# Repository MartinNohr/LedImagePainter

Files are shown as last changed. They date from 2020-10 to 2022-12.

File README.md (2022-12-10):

# LedImagePainter
New ESP32 version using rotary push button switch.
See https://www.thingiverse.com/thing:4613446 for details.
There is a switch in the .h file to add support for exFat (SDXC media) which will support SD cards > 32GB.
This library is needed: https://github.com/greiman/SdFat

See MagicImageWand for the very latest version of this project.

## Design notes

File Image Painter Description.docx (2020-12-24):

# LED Image Painter

# Introduction

## History

This design was inspired but not copied from the PixelStick commercial product. I have not owned, used or even touched an official PixelStick, I haven’t even read their manual. I did briefly look at the marketing material on their website to get an idea of how it worked. I was also inspired by the light wand developed by photographer Michael Ross. I started out building one of these. It used the Mega2560 Arduino and a 2-line display with some buttons. I started adding features and quickly ran out of memory. I also wanted to support a second 1-meter LED strip. At this point I decided to do a total rewrite and use the newer much faster esp32 modules. This let the feature list grow and the additionally the strip display speed was increased dramatically.

## Using with Your Camera

Put your camera on a tripod and set it for a long enough time exposure so the shutter is open for the time it takes to display the image. Stand at your chosen starting position and open the camera shutter. Press the Image Painter start button and walk from right to left (looking at the camera), or left to right if you prefer, it is adjustable from the menus. Walk smoothly or erratically for the effect you want and hold the wand in the same position or wave it around. Use your creativity and see what kinds of images you can create.

## Description

The Image Painter consists of the following major parts. The parts are all connected together into a single unit. The optional second LED strip is easily removed so the system fits into a smaller space.

1. LED strip. This is an aluminum extrusion with 144 LEDs and a diffuser cover. The LEDs are available with an adhesive backing that is used to stick the strip inside the extrusion.
2. Fixed Handle. The rotary control button is on the handle which is used to hold the Image Painter. The button is under your thumb and can be pushed and rotated.
3. Rotating Handle. This is useful when two LED strips are attached. It allows the user to spin the light stick.
4. Control Unit. This box holds the ESP32 computer that runs the LED strips and reads the rotary button switch.
  a. OLED Display. The ESP32 module used includes a small OLED display that is used to show the file selections. It is also used to show menus so that the various settings can be changed.
5. USB Battery. This is the rechargeable battery that runs the control unit and the LED strips.
6. Roller Encoder Wheel. This wheel is used to control the display speed while rolling on the ground. It will allow for very exact image timing. The good news is the software supports it, the bad news is that the hardware mount for the wheel has not been designed yet.

## 144 or 288 pixels

The Image Painter uses one or two WS3812B pixel strips that have 144 pixels per meter. In actuality each meter strip is made from two 72 pixel strips. This results in a slight gap in the middle that can be seen in some images. When the second strip is installed the power wires make it difficult to get the pixels really close. This also results in a dark gap in the middle of the two strips that can be seen with some images.

## Limitations

At full brightness each strip uses 43 Watts when all the LEDs are lit. Since the USB battery can only supply 35 Watts it is obvious that the display cannot be used at full brightness. However, some images do not have all of the LEDs lit at the same time so the brightness can sometimes be set to full power. For example, if the strip never has more than half of the LEDs on then the power consumption is only 21 Watts. This will work. In practice however I have found that due to the long night exposures it is seldom necessary to go brighter than about ¼ power.

## Processing BMP Images

The images can be either 144 or 288 pixels in height. They must be rotated 90 degrees CCW and saved as 24bit color in Windows byte order. They can be as long as desired in width.

# Examples

Here are a few example photos created with the Image Painter. People more creative than me will create much more interesting images. I’m including these just to illustrate a few simple examples. You can also go search the web for PixelStick images to get more inspiration.

# Button Operations

All operations can be controlled by the rotary push button on the handle, this makes the image painter usable with one hand. The display shows the options and settings and filenames. The dial can be rotated left or right to choose items. The button is clicked to select the current item. A long press is used to access other options and is done by holding the button down for about a ½ second or longer. This long press time is also adjustable if a longer or shorter time is preferred. The system has two modes of operation. After booting the display shows the currently selected file. Rotating the dial left and right will move through the files on the SD card, or the internal patterns if they have been selected. Clicking the button starts the LED strip display. At this point the user walks around with the wand or waves it around depending on what effect is desired. The display shows the progress of the file and how much time is remaining. Settings are available to control the display speed, repeating the file, or even automatically skipping to the next file. The image can even be played twice, first forward and then backward for a mirror like effect. There is a chain option that will play all of the files from the current selection to the final file in the current folder. The brightness of the LEDs are of course also adjustable to balance the lighting with the rest of the scene.

To adjust settings a long press is used which will open the last menu that was used. A long press while in the menus returns to the normal play mode. Each menu except the main menu has an entry to return to the previous menu.

## File Control Settings

There are more details below in the section on menus but here is a quick list of the things that can be changed for controlling the image display.

1. LED brightness.
2. Color Balance. Set the white balance for special effects or to correct color casts.
3. Gamma Correction. Adjust the display to match closer to our vision.
4. Frame hold time, how long each frame is displayed. Note that even when set to 0 there is a minimum frame time which is determined by the amount of time used to load the LED’s. See the menu section below for more details. Frame advance can also be set to manual so the frame only changes when the button is pressed or the dial is rotated.
5. Fixed display time. It is also possible to have the system calculate the frame hold time. You just set how long in seconds you want the image to take and it will set the correct frame time based on the image size.
6. Reverse. So the user can walk from left to right or vice versa.
7. Upside Down. This allows the user to hold the wand high in the air without modifying the image file.
8. Pixel Double. This uses two pixels for each one so a 144 pixel image can be displayed on the entire 288 pixels when two strips are installed.
9. Scaling. This will reduce a 288 pixel image to 144 pixels.
10. Mirror. Plays the file twice, first forward and then in reverse.
11. Chain. Plays all the files from the current file to the last file in the current folder. Files are always in alphabetical order.
12. Start Delay. A wait after pressing the button until the file starts. All delays are specified in 1/10 seconds.
13. Repeat Count. How many times to repeat a file.
14. Repeat Delay. A wait in between file repeats.
15. Chain Repeat. How many times to repeat a chain.
16. Chain Delay. A pause in between chain repeats.
17. Built-In or File. Choose files from the SD or from a set of built in patterns.
18. Change settings for various built-in patterns.
19. Select Folder. Choose a folder on the SD card to look for BMP files.
20. Display Settings. Control some menu operations and display options.
21. IPC. Manages files that change settings for folders and files. These setting files are loaded when a folder is selected or when a file is run. The settings for a file revert to the original values after running the file. These files are also text and can be edited if desired for special operations. The file version will apply the settings when the named file is displayed. The folder version is loaded when a folder is selected.
22. Saved Settings. Change the settings that can be optionally loaded at boot time. It is also possible to save the current settings and manually load them when needed.
23. Macros. There are ten macro slots (0 to 9) available. Each of these can either load all of the settings or run a recorded sequence of operations. The record command records the images as they are played and the same sequence can then be played again using the run command. The save command stores the current settings which can then be restored with the load command.
24. BLE. Enable BlueTooth. There is an Android app that can monitor and control the Image Painter. An iOS one may come later.
25. Reboot. This will reset the system. It can of course also be done by unplugging the USB power supply.

## Rotating and Clicking Button

The handle button is rotated and clicked to select different files, menu items, and to change settings. In the menus boolean values toggle with each click. Integer values go to another screen that shows the minimum and maximum values. Rotating the dial right increases the value while rotating to the left decreases it by the increment amount. The increment amount can be changed by clicking the button which will cycle between different values. One of the values will be a reset to the original value, activated with a long press. A long press is also used to accept the new value and return to the menu. A * indicates the active menu line. A + in front of the menu means another menu will be activated. The “Return…” menu goes back to the previous menu when clicked. A long press will return to file select/run mode. The current menu entry is remembered so that it will return to the same place when the long press is done from the select/run screen.

In select/run mode the current file is displayed on the top line. Optionally the next three files will be displayed below. Rotating the dial right moves the next file to the top line and rotating left moves the previous file back. By default it will stop at the first and the last file. An option allows rollover, so going left from the first file moves to the last file and moving right at the last file will display the first file again. This option also causes menus to behave similarly.

When a file is running after clicking the button the top of the display will show the progress of the file. The current filename is displayed. The line under the file will show the remaining seconds for the file. The rest of the screen will show the various delays, repeats, and chain information when those options are activated.

### Button Menu Operations

Left/ Right

Select menu

Select file

Inc/ Dec integers

Long press

Open menu system, goes to the remembered menu point

Return to run mode, the current menu point is remembered

Accept integer

Click

Run file when in run mode

Select menu item, including return to previous menu

Toggle booleans

# Menu Details

Following is a detailed list of all the menu entries and what they do. Menu items that open another menu (a submenu) start with a ‘+’. Most submenus also have a first and last menu entry that returns to the menu above. A ‘*’ is shown in front of the active menu line. The top menu will have a ‘-’ indicating that there are menu items that are not visible due to scrolling. Just keep rotating the knob to the left and they will appear. Similarly the last entry on the screen will have a ‘_’ if there are more menus below. Scroll right to make them visible as the ‘*’ indicator moves down.

The submenu details are also described below after each menu item.

## Main Menu

### Switch to Built-Ins/Switch to SD

Clicking this toggles between running files from the SD card or using the built-in patterns.

## File Image Settings

This submenu has the settings that control display attributes of the image files. The frame hold time is also used by some of the built-in image functions.

### Timing Type (Column or Image)

This is a Boolean that switches between using a set frame hold time for each column of the image file or a calculated time based on the desired total display time. It is sometimes more convenient to set the total time that the image file is displayed. This mode will automatically calculate the frame hold time such that the image will display for the chosen time. It is possible to request a time that is too fast for the image painter. If the calculated frame hold is less than about 4 mS the software cannot read the SD card fast enough to keep up. The image painter will try to do the best it can and the actual time will be displayed on the screen as the image plays.

### Frame Hold

When frame time is selected this is the time in mSecs (see note below) that each line of information from the BMP file is displayed on the LED strip. It is commonly used to adjust the walking time while the file is being displayed. It is only applicable when Frame Advance is set to auto.

Note: This time is actually added to the minimum time that it takes to update the LED’s in the strip. Each bit of information takes 1.2 uS and each LED needs 24 bits. If there are 144 LED’s then the total time to load the data is 1.2 uS x 24 x 144 = 4.32 mS. There is also a reset time at the end that loads the data into the LED’s of >50 uS. Some brands require up to 1 mS so it is safest to assume that the column update time is about 5 mS. This time is added to the time set in the frame hold value, I.E. a hold value of 0 will still have a 5 mS frame time. There might also be additional time required for reading slower SD cards. Also be aware that displaying the file in reverse will slow down due to reading the SD file in the reverse order. A 900 column image would in theory take about 3.9 S. In testing we have found that reading the SD card actually slows this down to about 6 Seconds. Work is being done to try and improve this.

### Fixed Time

When fixed time is selected as described above in Fixed/Frame Time this menu item allows the time to be set in seconds that the image will be displayed. The necessary frame hold time will be calculated and used while displaying the image file. This value will not be saved in the frame time so if frame hold is selected it will show the original value.

### Frame Advance

The options are “auto” and “manual”. In auto mode the frame hold time is used. In manual each line is displayed until the button is pressed, the dial is rotated, or the wheel pulse counter closes the contact. If the frame pulse counter is zero then the dial is used to advance frames. Rotating to the right or clicking will display the next frame from the file. Rotating to the left will display the previous frame. This enables some creative uses of image by rotating the wheel left and right. Note that the mechanical wheel pulse counter has not been designed yet.

### Frame Pulse Counter

This value is the number of wheel pulses that will advance to the next frame when manual frame advance is set. Note that this disables using the rotary dial to advance frames.

### Start Delay

This value delays the image display after the start button is pressed. It can be set in 1/10 seconds.

### Upside Down Image

When set, the image pixels will be reversed. This allows the LED bar to be held upside down without making the image upside down.

### Walk Direction

This option changes the direction that the file is read. This allows the image to play forward or reverse. This allows the user to walk in the other direction or to simply reverse the image from left to right. The default is right to left, looking back at the camera. Right to left is usually best when recording a sequence of images into a macro. The images will then play back in the same order. If left to right is chosen then the images recorded will play back in the reverse order. This is particularly important when spelling words with the individual letter image files.

### Play Mirror Image

This plays the image twice, once forward and then in reverse. This creates a mirror like effect.

### Scale Height to Fit

If the image is taller than 144/288 this option will ignore some pixels so that only 144/288 are actually displayed. It doesn’t do any fancy scaling like Photoshop by looking at adjacent pixels, it simply ignores some of them so the image will fit.

### 144 to 288 Pixels (only when 2 strips)

This doubles every pixel so a 144 pixel image will fill all 288 pixels. Of course there isn’t any increase in resolution, but it does fill two strips if you don’t have a 288 pixel image.

## Repeat Settings

This submenu contains settings that are used to repeat images. Except for the chaining option it also applies to built-in images.

### Repeat Count

This is the number of times to repeat an image.

### Repeat Delay

When repeat count is greater than one this value will cause a delay before the image starts again. It can be in 1/10’s seconds.

### Chain Files

When this option is on all the files from the current one to the end of the last file in the current folder will be displayed. Since filenames are always sorted alphabetically this option will show a sorted list of files. If some other order is desired it is also possible to use the macro command to record the file order for display.

### Chain Repeats (only when chain files on)

The entire chain will be repeated this many times.

## LED Strip Settings

This submenu has settings for the LED strip.

### Strip Brightness

This is the brightness from 1 to 255. It was originally from 1 to 100%, but it was found that this didn’t give very fine resolution of brightness on the low end, so it was decided to use the actual hardware value which has 255 level, not 100.

### LED Strips

This is set to “one” or “two” depending on whether you have the second strip installed. The designer didn’t figure out any way to automatically detect the second strip.

### Gamma Correction

This option modifies the displayed colors at different brightness levels to more closely match our eyes color perception.

### White Balance R

This manually sets the strip Red brightness.

### White Balance G

This manually sets the strip Green brightness.

### White Balance B

This manually sets the strip Blue brightness.

### Show White Balance

Selecting this displays the before and after result of setting the RGB levels.

## IPC File Operations

IPC files are files that can load settings and display images. They are text and can be modified by using any text editor on them. The extension is always IPC (Image Painter Command). There are menu items to create, run and delete them. Depending on the name some of them are automatically run under certain conditions as documented below.

IPC file only control the settings for files, none of the built-in image settings are saved in these files.

### Save start.ipc

This creates a file with the current settings. It is run whenever a folder is opened.

### Load start.ipc

This will manually run the file in the current folder.

### Erase start.ipc

This does just what it says: removes the start.ipc file from the current folder.

### Associated Files

These are command files just like the start.ipc file above, but they have the same name as a BMP file, but with the .ipc extension of course. The file is run when a BMP file is started for display. This allows specific settings to always be applied to a specified BMP file.

#### Save <filename>.ipc

This saves the current settings for the currently selected BMP file.

#### Load <filename>.ipc

This loads the settings for the currently selected BMP file. It can be used to verify that the settings are in fact correct.

#### Erase <filename>.ipc

This command deletes the file associated the currently selected BMP file.

## Macros

Macro files are a powerful feature that can be used to record and run a set of images. There are 10 macro files allowed. They are named from 0.ipc to 9.ipc on the SD card in the root folder. They can also be edited on a computer by using a text editor if necessary. The easiest way to create one is to use the record menu entry as shown below.

### Macro #(0-9)

This selects the current macro number. It shows a list of all the macros along with information on whether it already exists or not. Clicking on a line makes that macro # the active current macro # which is used by most of the following menu entries.

### Run

This will run the currently selected macro number.

### Repeat Count

This value repeats the macro run.

### Repeat Delay (S)

There can be a delay between each run of the macro when repeat is on.

### Recording

When set to true the settings and displayed images will be appended to the currently selected macro number. It should be turned off when all the actions have been recorded. Is the delete command if a sequence is to be started without appending.

### Load

This loads the settings in a macro file. It is best used in combination with the save command.

### Save

This saves the current settings in a macro file.

### Delete

This erases the currently selected macro file. It is useful when a new sequence is to be recorded since the default record action is to append new actions.

## Saved Settings

These settings are stored in the EEPROM section of the ESP32 and is a useful way to set all of the defaults during boot time.

There is a version number stored in EEPROM that will be compared when loading. I mismatch will cause an error message to appear. Saving the settings will clear this error.

### Autoload Saved

This flag causes the EEPROM values to be loaded at boot time. If off then the factory settings will be loaded instead. If factory settings are desired the button should be pressed during booting. This will ignore the setting of this flag.

There is some quirkiness in the code that will not allow this flag to be turned off until the settings have been saved at least once. This only happens the first time the software is loaded on a new ESP32 board. Using the “save current settings” command will fix this forever.

### Save Current Settings

This saves the current settings. Built-in options settings are also saved. Note that IPC files do note save any of the built-in settings.

### Load Saved Settings

This manually loads the settings from EEPROM.

## System Settings

Various system settings can be changed from this submenu. These include the display and various operations.

### Display Brightness

This is the TFT display brightness from 1 to 100%. It is often desirable to lower it when working in strong darkness.

### Display (Normal or Reverse)

This option reverses the colors on the display.

### Menu Wrap

When this is off scrolling of both files and menu items is pinned at the top and bottom of the list. If wrap is on then rotation the dial to the right when at the last entry will go to the first entry and rotation left from the first entry to move to the last entry.

### Show More Files

In run mode the top line always shows the file to be displayed. When this flag is on the following lines on the display will show the next few files in the current folder.

### Show Folder

The top line in run mode shows the current file to be run. If this flag is on it will include the folder path. It should be turned off if the folder path is too long.

### Progress Bar

When a file is running the top of the OLED display can show a progress bar. This option is used to turn it on or off.

### Dial (Normal or Reverse)

This sets the direction of the dial that moves forward or backward through choices.

### Dial Sensitivity

It is sometimes desirable to reduce the sensitivity of the dial to rotation. Wearing gloves or shivering fingers is an example. This allows a counter to be set such that more than one rotation detent will be required to produce a dial motion. For example, setting this to 2 means that the dial has to be moved two clicks before it would change the selection. Values from 1 to 5 can be set.

### Dial Speed

This value adjusts how fast the dial needs to be moved to work with the dial sensitivity setting. It is effectively the time between clicks. It can set from 100 to 1000 and is approximately a time value in mSeconds. If you have the sensitivity set to a number greater than 1 then you have to rotate the dial faster than this number allows in order to cause the selection to change.

### BlueTooth Link (On/Off)

This enables the BlueTooth link to be used with the phone app for control of the Image Painter.

## Light Bar

This selection turns the Image Painter into an adjust LED light source. All of the LED’s are turned on. The menu can then be used to change the Hue, saturation, and brightness levels. The maximum brightness is limited by the strip brightness that is set in the strip menu. This may be changed in the future so it will be possible to increase the brightness beyond that setting. Anybody have any strong thoughts on that?

The default allows setting the brightness, hue and saturation, but it can also be changed to use RGB values. The default increment unit is 10 for each click of the dial but that can also be adjust for finer resolution.

A long press is used to turn the light bar off again.

## Reboot

Just like unplugging the power and plugging it back in.

# Built-In Patterns

There are a number of built-in pattern generators. Some of them have settings that can be adjusted from the entry that appears on the first menu when a particular built-in is selected. The available built-ins are listed below.

## Barber Pole

This creates a rolling red, white, and blue pattern. It will create diagonal patterns. The speed is controllable by setting the frame hold time.

## Beats

Colored bars moving up and down.

## Bouncy Balls

This uses physics calculations to simulate some colored bouncing balls. The number of balls can be set up to 8, each will have its own color. The speed can be changed using the same built-in menu. The frame hold time is not used. On an image it makes some interesting decaying inverted second order polynomial traces. Sorry about the math terms! Play with it.

## Checker Board

Alternating black and white boxes. The speed is adjustable using the built-in menu or the frame hold time.

## Confetti

Interesting color dots that appear and then fade out.

## Cylon Eye

This was inspired from the BattleStar Galactica movies, the evil Cylon eyes.

## Juggle

This shows some color bars that move up and down and cross over each other.

## Meteor

This looks kind of like a meteor moving from one end of the strip to the other.

## One Dot

Actually, this is four dots, red, green, blue and white. They move one at a time from one end to the other. It is probably mostly useful for testing the wand. That’s why it was written originally.

## Rainbow

The color, number of repeats, and color cycling can be controlled. It is even possible to add random sparkles to add a bit more interest. Try moving the wand in an arc for interesting rainbow-like patterns.

## Random Bars

This produces solid colors that alternate randomly. An option sets black in between each color bar. Waving the wand can make some interesting patterns in the air.

## Rainbow Pulse

This is rainbow that starts from the bottom, sweeps up, and then back down again until it is gone.

## Sine Trails

A little more math here traces a color blob using the sine function.

## Solid Color

This is probably one of the more useful patterns. It allows the LED strip to be used as a light source. The color can be controlled with the dial as well as the saturation and brightness. A setting allows the RGB values to be entered if that is desired. The brightness value is limited by the LED strip brightness setting from the main LED settings menu. So if more brightness is needed that value must be changed. The LED strip will stay on until a long press turns it off.

## Twinkle

A display of dots of various colors that change color randomly.

## Two Dots

This is like the One Dot, except that two dots are on the strip. They start at opposite ends and cross over in the middle. It was also written originally to test the code and the LED strip.

# Menu structure

Here is a chart of the menus. Note that menus that are not applicable will not be displayed. For example, choosing Frame Time means that Fixed Time will not appear in the menu while choosing Fixed Time means that Frame Hold won’t appear.

File Image Settings
Repeat Settings
Fixed/Frame Time
Frame Hold
Fixed Time
Start Delay
Repeat Count
Chain Files
Chain Repeats
Frame Advance
Frame Advance Counter
Upside Down Image
Direction
Play Mirror Image
Scale Height to Fit
144 to 288 Pixels
Repeat Delay
LED Strip Settings
Strip Brightness
LED Strips
Gamma Correction
Main Menu
IPC File Operations
Save start.ipc
Load start.ipc
Erase start.ipc
Associated Files
Save <filename>.ipc
Load <filename>.ipc
Erase <filename>.ipc
Macros
Macro #(0-9)
Run
Repeat Count
Repeat Delay
Recording
Load
Save
Delete
Saved Settings
Autoload Saved
Save Current Settings
Load Saved Settings
System Settings
Display Brightness
Menu Wrap
Show More Files
Show Folder
Progress Bar
BlueTooth Link
LIght Bar
Reboot
Dial Direction
Dial Sensitivity
Dial Speed

# Construction

Yes, there are a few parts and a fair amount of wiring and soldering to do. If you aren’t comfortable soldering, find someone who is! The wiring harnesses are probably the most work to make, but they are essential in order to hook everything up. I will include a photo of the ones I make that should make it easier to duplicate. Looking at the schematic will help understanding what is connected to what. The 3D printed parts can be purchased from me if you can’t find anybody else to make them from the STL files. I print currently using PLA, so please don’t leave them in the sun, they will melt and deform if it gets too hot!

All of the screws are metric and should be available from a well-stocked hardware store. I got mine from Ace Hardware.

All of the electronic components and the aluminum channel are available from Amazon. They are likely also available from other vendors. I bought the aluminum shiny ones because I didn’t find the black anodized ones until later. Some people worry that the shiny aluminum will show in the final image. In practice I haven’t seen this, but I do plan to start using the black one after I finish using all the shiny ones I have in a box! I got the WS2812B LED strips from BangGood.com in China. Aliexpress.com also carries the WD2812B. Be aware that the shipping time from China can be quite long. Amazon is faster.

I am considering making a parts bag available with all the hardware parts needed. I buy them in quantity so it would be easy enough to put a bag together.

You can solder up a bunch of wires and connectors to connect everything inside the cpu/display box like I did for my first prototype, but I have designed a printed circuit holding all the parts and I can sell those for $10+shipping. It does make the assembly much less painful. I can also make the PCB version available with the ESP32 already soldered and programmed.

## Parts List

### Electronic Parts

1. Heltec ESP32 Devkit32. https://www.amazon.com/gp/product/B07DKD79Y9/ref=ppx_yo_dt_b_search_asin_title?ie=UTF8&psc=1
2. Micro SD card reader. https://www.amazon.com/gp/product/B07BJ2P6X6/ref=ppx_yo_dt_b_search_asin_title?ie=UTF8&psc=1
3. Rotating switch. https://www.amazon.com/gp/product/B07DM2YMT4/ref=ppx_yo_dt_b_search_asin_title?ie=UTF8&psc=1
4. USB rechargeable battery. https://www.amazon.com/gp/product/B07MCDT8FW/ref=ppx_yo_dt_b_asin_title_o00_s00?ie=UTF8&psc=1
5. USB connector. https://www.amazon.com/gp/product/B072DWP59M/ref=ppx_yo_dt_b_search_asin_title?ie=UTF8&psc=1
6. Logic level shifter. https://www.amazon.com/gp/product/B07LG646VS/ref=ppx_yo_dt_b_search_asin_title?ie=UTF8&psc=1
7. 5 pin, 4 pin, and 3 pin connectors. https://www.amazon.com/gp/product/B07GGPQXFC/ref=ppx_yo_dt_b_search_asin_title?ie=UTF8&psc=1 https://www.amazon.com/gp/product/B075K3M1TB/ref=ppx_yo_dt_b_search_asin_title?ie=UTF8&psc=1 https://www.amazon.com/gp/product/B075K6N7DF/ref=ppx_yo_dt_b_search_asin_title?ie=UTF8&psc=1
8. LED channel. https://www.amazon.com/gp/product/B01LL2SLME/ref=ppx_yo_dt_b_search_asin_title?ie=UTF8&psc=1
9. WS2812B LED strips. https://www.amazon.com/gp/product/B07BKQZLDL/ref=ppx_yo_dt_b_search_asin_title?ie=UTF8&psc=1

### 3D Printed Parts

1. Battery holder.
2. Rotating handle base.
3. Rotating handle.
4. Electronics box. There are two of these, one for the PCB, and one for discrete parts.
5. Handle.
6. LED strip end protectors.

### Software and Libraries

I will make a compiled binary available on the github entry for this project if you don’t want to collect all these files and compile the code. It can be built with the Arduino IDE, but I personally prefer Microsoft Visual Studio Community version along with the Visual Micro extension for Arduino, which is a bargain at $19/year.

https://github.com/MartinNohr/LedImagePainter

1. Arduino IDE, Visual Studio Code, or Microsoft Visual Studio with Visual Micro or any other development system that can compile the C and C++ code for the ESP32.
2. ESP32 support libraries for Heltec wifi devkit32
3. ArduinoJSON library (the one by Benoit Blanchon)
4. FastLED library
5. Ringbufcpp library (this is not used in the latest version of the software)
6. Stackarray library

### Wiring Harnesses

These are somewhat time consuming to make. Soldering skills are required. See pictures for what they look like.

1. Internal, for SD card reader, level shifter, LED/Power, and rotating button.
2. Battery and LED’s.
3. Rotating button.

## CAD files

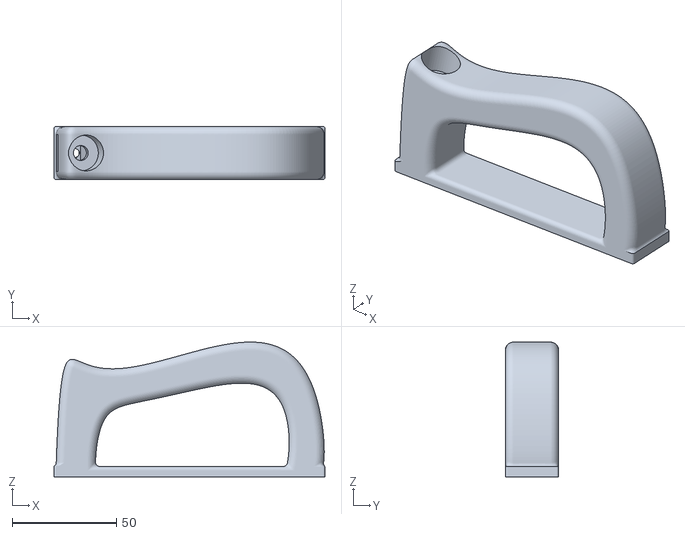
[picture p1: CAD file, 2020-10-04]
handle with angle v25.stl
130.0 x 25.6 x 64.7

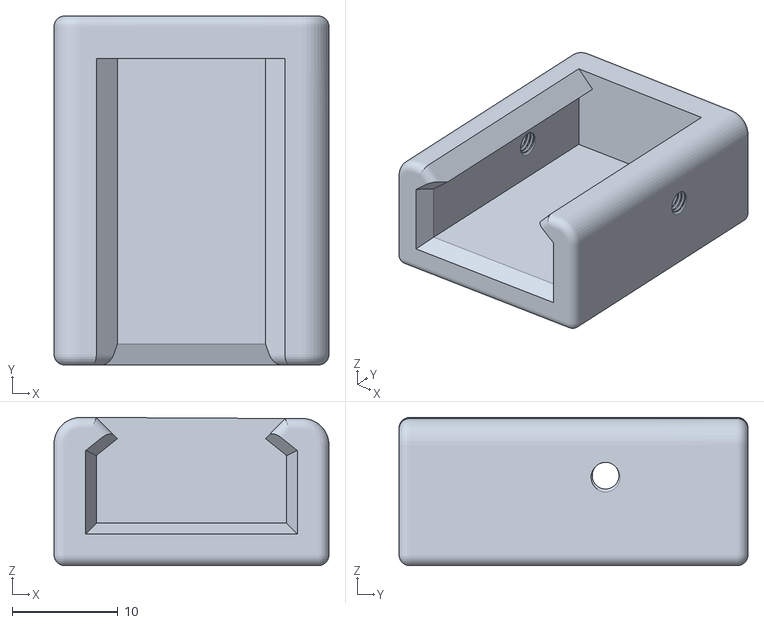
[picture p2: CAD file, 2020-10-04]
strip bumper v3.stl
26.0 x 33.0 x 14.0

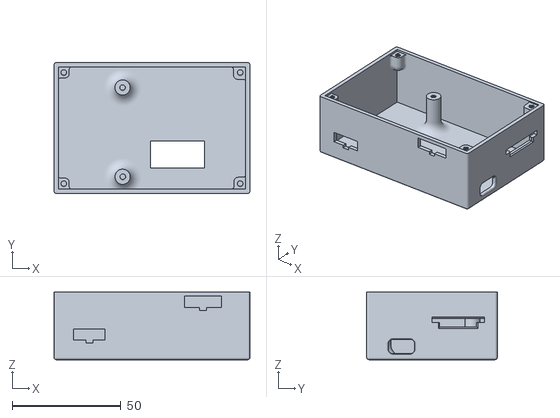
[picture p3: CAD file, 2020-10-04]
esp32 PCB 1 case v27.stl
90.0 x 60.0 x 31.0

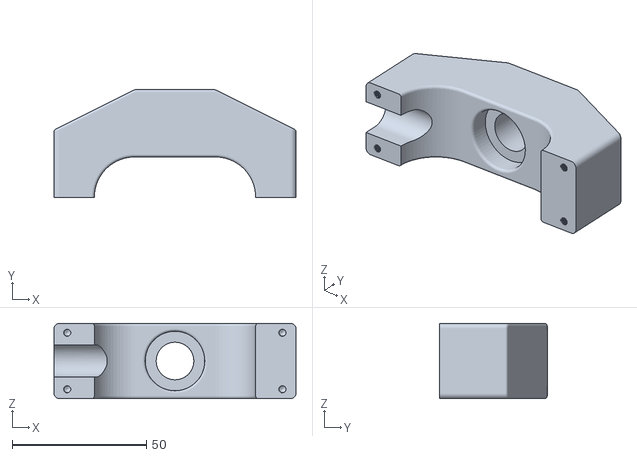
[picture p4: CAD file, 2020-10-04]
esp handle tower v8.stl
90.0 x 40.0 x 28.0

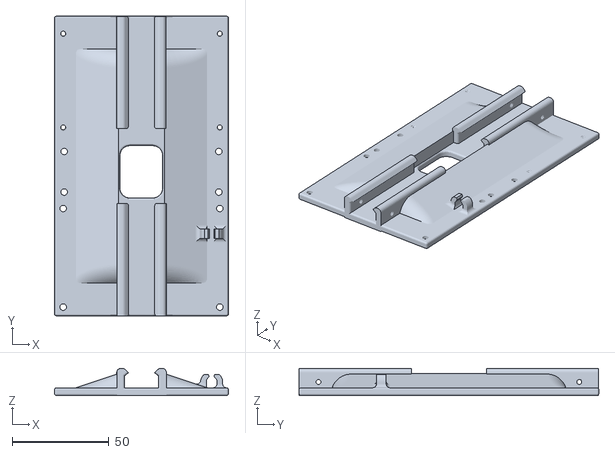
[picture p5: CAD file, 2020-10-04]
esp horizontal base v35.stl
90.0 x 155.0 x 14.0

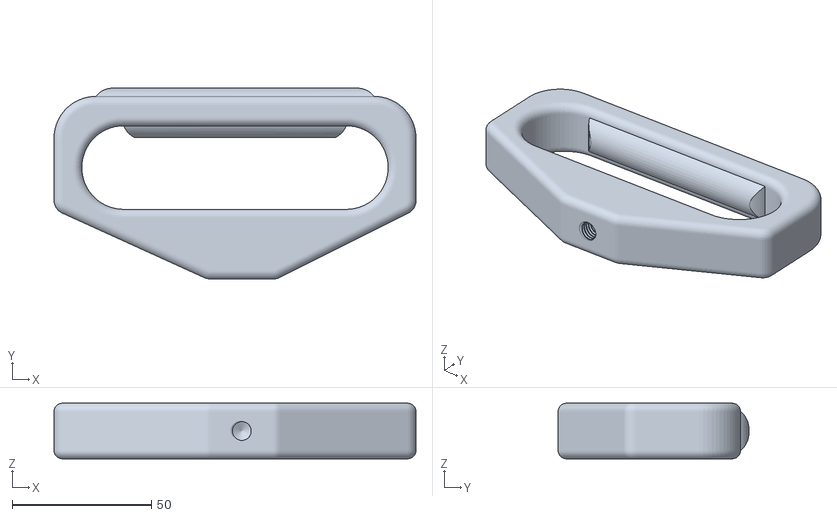
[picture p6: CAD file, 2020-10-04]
esp Spinner Handle v2.stl
130.0 x 68.6 x 20.0

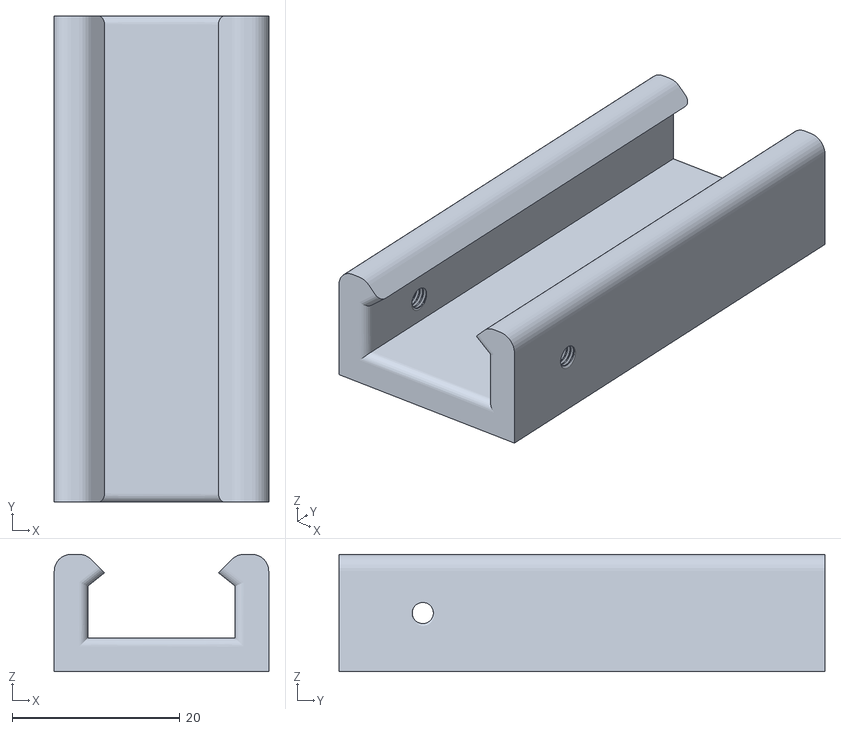
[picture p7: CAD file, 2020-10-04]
strip clamp short v23.stl
25.6 x 58.0 x 14.0

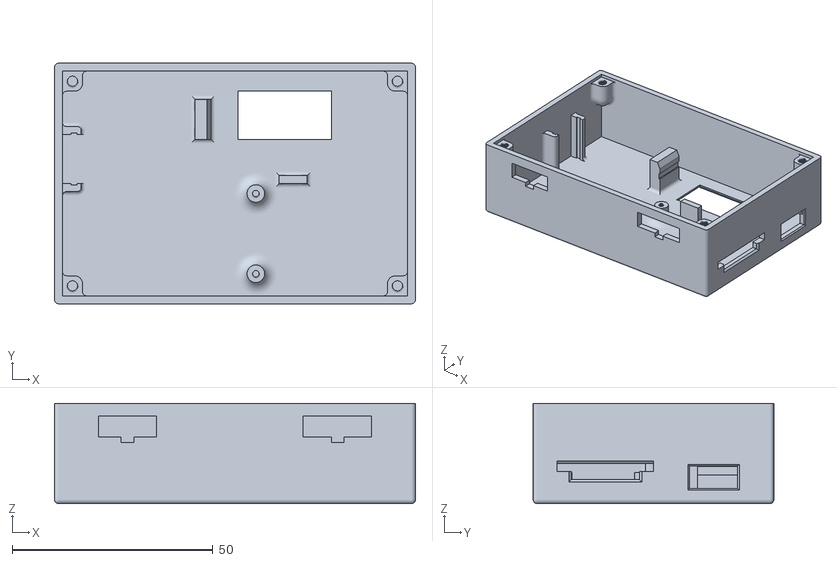
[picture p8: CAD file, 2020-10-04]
esp32 horizontal no PCB v9.stl
90.0 x 60.0 x 25.0

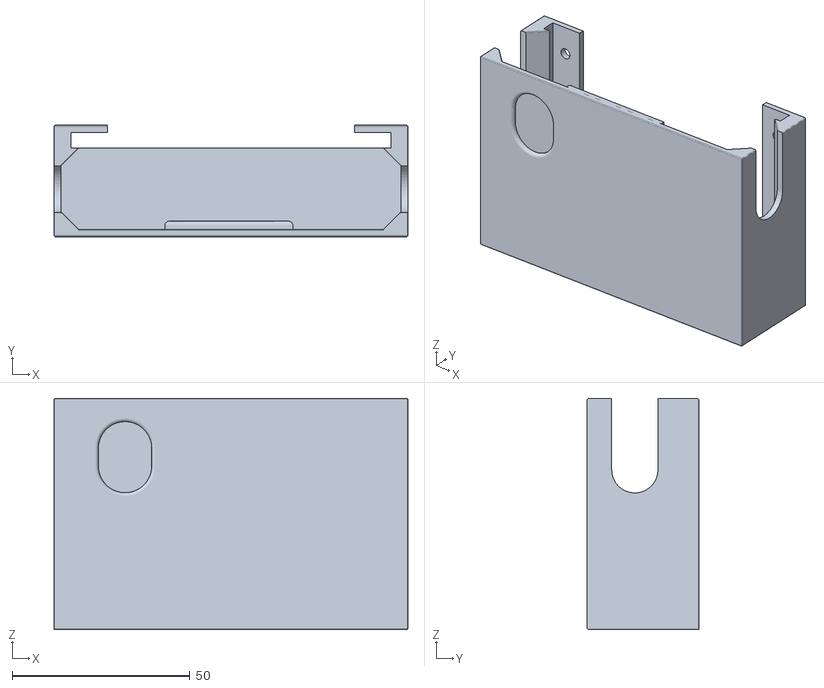
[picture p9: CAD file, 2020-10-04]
esp32 horizontal battery v30.stl
99.6 x 31.4 x 65.0

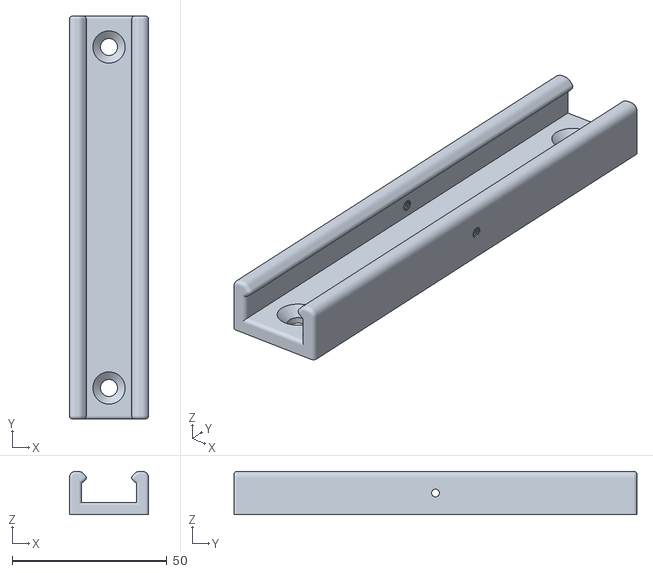
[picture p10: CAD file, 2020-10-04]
handle mount base v6.stl
25.6 x 130.0 x 14.0

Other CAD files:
esp Spinner Handle v2.f3d
esp handle tower v8.f3d
esp horizontal base v35.f3z
esp32 PCB 1 case v27.f3d
esp32 horizontal battery v30.f3d
esp32 horizontal no PCB v9.f3d
handle mount base v6.f3d
handle with angle v25.f3d
strip bumper v3.f3d
strip clamp short v23.f3d

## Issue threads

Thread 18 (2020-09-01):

Manual frame advance left and right

MartinNohr, 2020-09-01:
It might be nice if the frame advance went to the previous frame when the dial is rotated left and the next frame when rotated right.

MartinNohr, 2020-11-15:
This was fixed a long time ago, I forgot to close this comment.

Closed 2020-11-15.

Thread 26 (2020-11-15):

Command readByte in LedimagePainter

Beschuitbus, 2020-11-15:
Hello,
I'm using Arduino IDE and try to compilate the LedImagePainter.ino.
But I get an error for the command readByte: readByte' was not declared in this scope

In which library can I find readByte?

MartinNohr, 2020-11-15:
It isn't in a library, it is in the LedImagePainter.ino file. I haven't tried compiling with Arduino IDE, I use Microsoft Visual Studio, but it calls the same compiler so it should work.
Did you select the correct processor? Heltec ESP32.
int IRAM_ATTR readByte(bool clear) {
The IRAM_ATTR is only available for ESP32 I think.
If that is correct, send me more information, like which line the error occurs on and the complete error message.
If I have time today I'll try and compile with Arduino IDE and see if it works.

MartinNohr, 2020-11-15:
OK, I see what it is, MSVC handles forward references differently than Arduino IDE. I'll fix and check in a new version.

MartinNohr, 2020-11-15:
OK, I fixed the code for the Arduino IDE.
Remember to comment out a line for the original schematic. I made a mistake on the PCB layout.
// SB with rotary switch, comment out for original schematic
#define PCB_WITH_DIAL 1
Also remember to configure Arduino IDE for partition: Huge model or it won't compile.

MartinNohr, 2020-11-16:
Is it working for you now? If so, I'll close this issue.

Beschuitbus, 2020-11-16:
Hi Martin,

Thanks for your quick responce and soluction.
I've compiled it with ArduinoIDE and it compiled without errors.
I'm waiting for some parts (from china) before I can test it.

Again thanks for the good work.

Regards
Cor

Op ma 16 nov. 2020 18:50 schreef MartinNohr <notifications@github.com>:

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

MartinNohr, 2020-11-17:
Make sure you comment that line I mentioned or the pins for the switch will be wrong for the schematic. I accidentally changed them when I had the PCB made. I'm redoing the PCB and I will fix those pins again so they match the original schematic. If the switch isn't working then that is likely the problem.

MartinNohr, 2020-11-17:
Glad you got it to compile. Next wire it up and see if you can get it to work! Let me know if you have any problems.
I would also greatly appreciate it if you have any suggestions for improvements.
I am also making a new version that will work on the TTGO with the color display. It has a higher resolution, and colors! Among other things I'll be able to display the bmp files on the display. The main advantage will be that the menus can be made nicer with the use of colors.

MartinNohr, 2020-11-17:
Here's the pcb version.
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

Beschuitbus, 2020-11-18:
Thanks voor the warming, I had already comment that line.
I' m stille waiting for the parts, expecting 5 dec. Then I can start
testing. 3d printer is already running for some parts.
I adapted a tripod mount to the handle and rotating handle.

Regatta
Cor

Beschuitbus, 2020-11-19:
Some question for the build:

1. Where do I connect the data to both led strips? In the middle of the stick, separately on both strips (from output 17 and 25) or led1 at the bottom of the stick and at led2 in the middle of the stick?
2. According to the schematic you do not use the 470 ohm resistor at the beginning of the data of the strips, which is advised to avoid spikes that can damage the first pixel (https://learn.adafruit.com/adafruit-neopixel-uberguide/best-practices)
3. You also don't use a capacitor between the + and - terminals?

MartinNohr, 2020-11-20:
You should add that 470 ohm resistor. I forgot, oops. I'll add them to the next version of my PCB. The data lines are both in the middle of the stick when using two. I reverse the data in software going to the bottom stick to deal with that. I originally ran the wire down to the bottom but that seemed silly and messy. Led1 is the bottom stick and Led2 is the upper one.
There should probably be a capacitor across the +- of each strip. I watched the signals with my 'scope and never saw any real problems so I didn't bother. Still, it is probably a good idea.
About the 470 ohm... since I used a PCB and the wires aren't exposed it probably isn't a big deal, there won't be any spikes coming from the logic level converter. But, you never know!

MartinNohr, 2020-11-20:
Thanks for the question on where to hook up the data lines. I will make that clear in the documentation somewhere.

MartinNohr, 2020-11-20:
BTW, the reason I used two control pins from the ESP32 is exactly because I wanted to avoid running the wire down the length of the strip. My original design just chained the two strips and used one control pin. I didn't like that long wire!

MartinNohr, 2020-11-27:
I just noticed that I broke something in the code for the second LED strip. Oops! I'll fix it in the next couple of days.

MartinNohr, 2020-11-27:
Fixed two LED strip handling.

MartinNohr, 2020-12-02:
> 2. According to the schematic you do not use the 470 ohm resistor at the beginning of the data of the strips, which is advised to avoid spikes that can damage the first pixel (https://learn.adafruit.com/adafruit-neopixel-uberguide/best-practices)
I didn't worry about those "spikes" because of the way the connections are on the PCB. I don't think it is possible to get spikes from the level translator I'm using. So it should be safe.

MartinNohr, 2020-12-28:
The TTGO version is now working. It uses the TTGO T-Display version. It has a lovely color screen. I added the ability to preview the BMP files on the screen.
https://github.com/MartinNohr/MagicImageWand

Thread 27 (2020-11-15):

I made it.

zhaoyu3517, 2020-11-15:
I made it.Thank you for your code.
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

I use the  ESP32-DevKit+0.96OLED，2*18650 Batteries and XL4105 DC-DC Buck Converter Step Down Module as power.

MartinNohr, 2020-11-15:
Very nice. I thought of using a few 18650 batteries also, they can supply more power to the lights.
Here is my latest version. I put all the electronics on a PCB and it is nice and small now.
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

MartinNohr, 2020-11-15:
I like your idea of using 18650, that would make mine even smaller.

MartinNohr, 2020-11-15:
You could use 4 batteries, 2 series, 2 parallel to get more current, this would allow much more brightness. Those LED strips can use 35Watts.

MartinNohr, 2020-11-15:
I think you meant XL4015, not XL4105, module.

MartinNohr, 2020-11-15:
What does the Chinese say in your sample photo?

MartinNohr, 2020-11-15:
There is sleep command in the main menu that has been commented out. It doesn't work with the USB power supply but it would work with your batteries. The USB box shuts down if there isn't enough current draw. WIth your batteries it would reduce the power usage a lot. It does need to be improved though, it doesn't remember the current settings, so it is like a restart when you click the button. That would be pretty easy to change, I'll do it when I have a little time.

zhaoyu3517, 2020-11-15:
I use translation software to convert it into English, so sometimes I don't get it right. I use 2 series batterie by one LED strips.If two LED strips I will use another batterie.One xl4015 can withstand 5A current. Two LED strips need 2 group 2 series batterie and 2 xl4015. In Chinese it means “I work hard every day”.:-)

zhaoyu3517, 2020-11-15:
This is XL4015 Module.
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
We can use this Battery.It provides a higher current.
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

MartinNohr, 2020-11-17:
Here's the PCB.
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

zhaoyu3517, 2020-11-18:
It is great！I am also making a new version, lighter weight and smaller size.

zhaoyu3517, 2020-11-18:
I will wait for your TTGO version and remake it. What version of TTGO will you use？

MartinNohr, 2020-11-20:
TTGO t-display. I have part of it working already. Color screen is much nicer. I have also added the lion battery internally to run the TTGO and the external battery to run the led strip. I added a sleep mode so none of the settings are lost during sleep. Touch the button and it immediately wakes up and works with the same settings as before. I'm glad you made one and hope you are enjoying it. It is fun to make creative photos using it.

MartinNohr, 2020-11-27:
Have you tried using 2 LED strips? I just hooked up my second strip and it appears that the code is broken, the second strip does not always work correctly. I'll figure it out and fix it later this week. I remember changing some code there last month and I think I did something wrong!

MartinNohr, 2020-11-27:
I fixed the code. It was caused by the remapping of pixel address stuff I did to get rid of the wire running down to the bottom of the first LED strip. Maybe that wasn't so smart. Anyway, it works now.

zhaoyu3517, 2020-11-28:
I‘m not tried using 2 LED strips，I haven't figured out how to fix it.I am waiting for my Water-Washable Resin,to make a new handle.

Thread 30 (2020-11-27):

Two strip rainbow not working

MartinNohr, 2020-11-27:
The lower strip is actually upside down because the fastled library doesn't know about the reverse addresses for the first strip that I did to get rid of the wire down the strip to the bottom. I'll have to give some thought how to fix this, I don't want to change the fastled library.

MartinNohr, 2020-12-02:
Fixed.

Closed 2020-12-02.

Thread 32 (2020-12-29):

Chained files don't work in folders

MartinNohr, 2020-12-29:
The chain option fails when in a folder.

MartinNohr, 2020-12-29:
Fixed in the latest code. It was caused by count files only function not working correctly.

Closed 2020-12-29.

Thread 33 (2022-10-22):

Accelerometer

breakingcraft, 2022-10-22:
Would it be possible to add an accelerometer to print the image instead of using a Fixed Frame Time? Like the MPU-6050.
As you are slower to move in the beginning of the picture it can make pictures very distorted in the start, the faster the acceleration gets the faster the next frame will print. So technically you could stop in the middle of the picture and then walk again and it would show even frames throughout the whole picture.

MartinNohr, 2022-10-22:
Excellent idea! And I have even already been thinking about it. I have a model working here that shows what angle you're holding the wand at. I haven't added any code to do what you are suggesting but that is a great idea. I am redesigning the PCB and I think I will add the MPU-6050 to it. I'm also switching to an ESP32 TTGO that has a larger display. No promise on the deadline though. :-(

MartinNohr, 2022-10-22:
One more thing I added to the new code in "MagicImageWand" is support for an encoder wheel that you can roll on the ground. The frame advancing is controlled by pulses from the encoder. It solves the same problem in a different way. Unfortunately, the code is done, but I haven't finished the design of the wheel yet.

breakingcraft, 2022-10-23:
Good to know which version of MagicImageWand you are development, it was a bit confusing to know where to comment.
I really like the ESP32 TTGO, keep up the good work!
I will try out the encoder part.

MartinNohr, 2022-10-24:
I have tested the code by grounding the wire a few times. It advances one frame each time so it should work with an encoder wheel. I'm also getting the code to work on the new ttgo s3, larger display!

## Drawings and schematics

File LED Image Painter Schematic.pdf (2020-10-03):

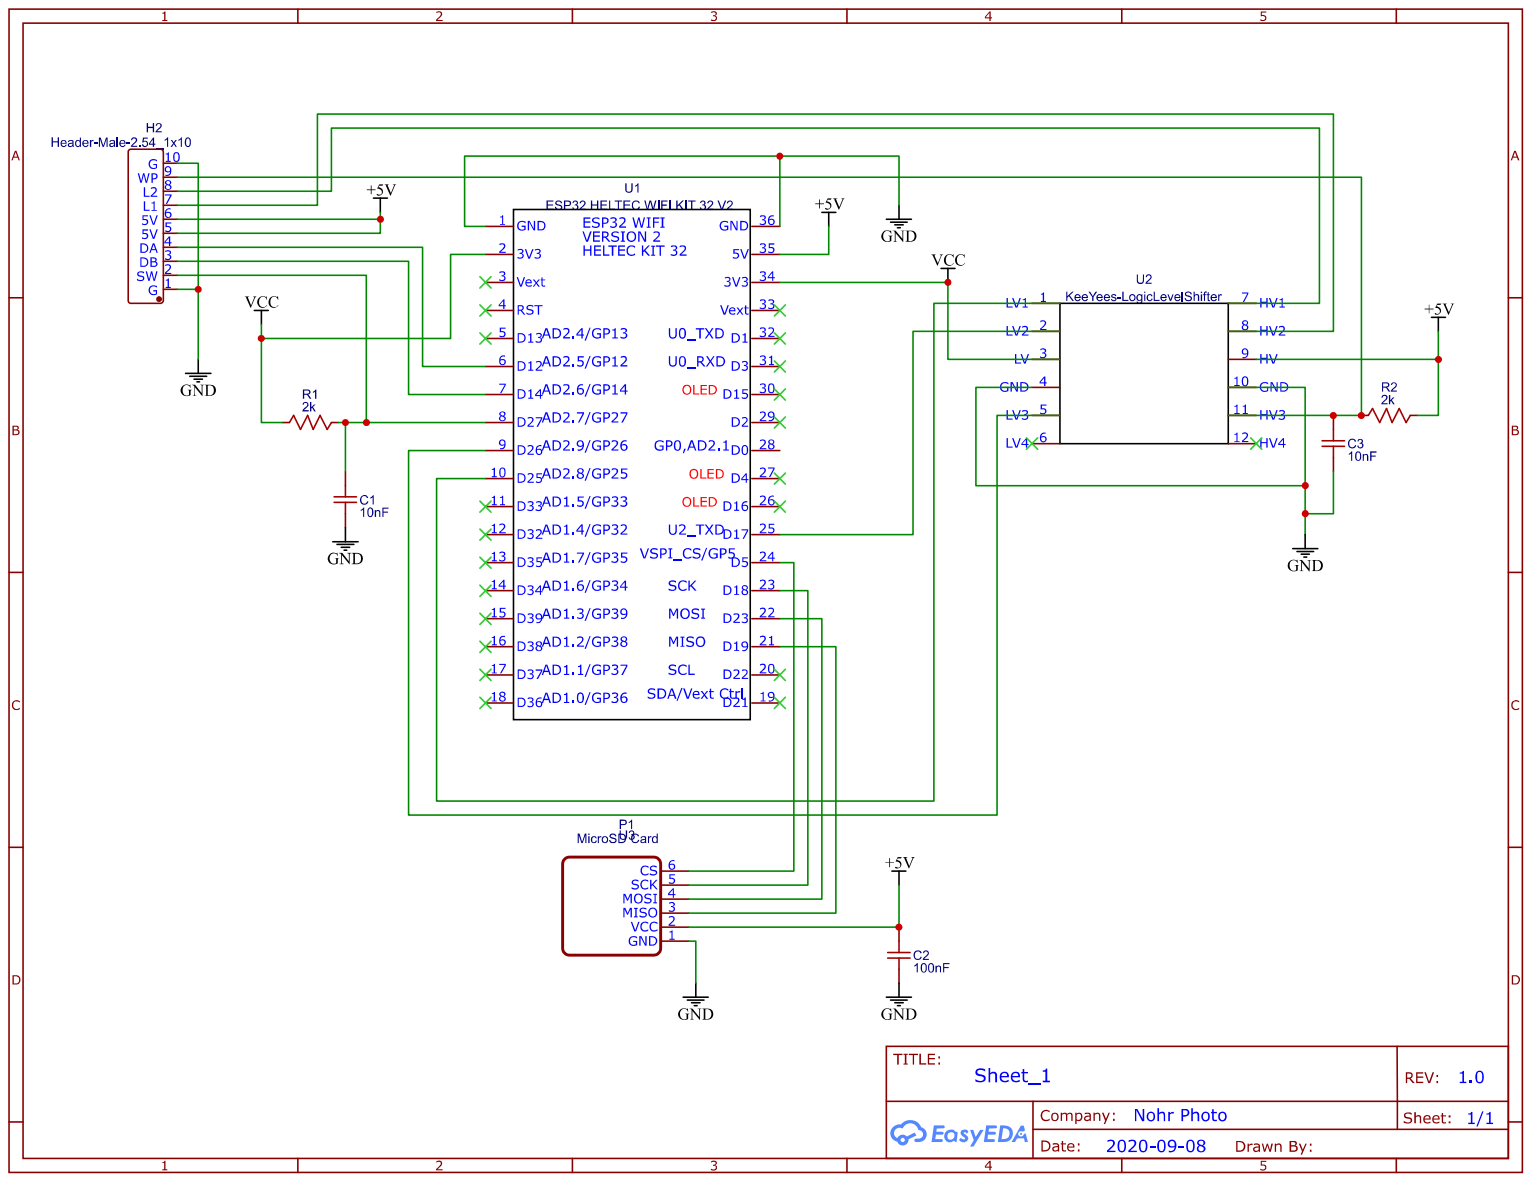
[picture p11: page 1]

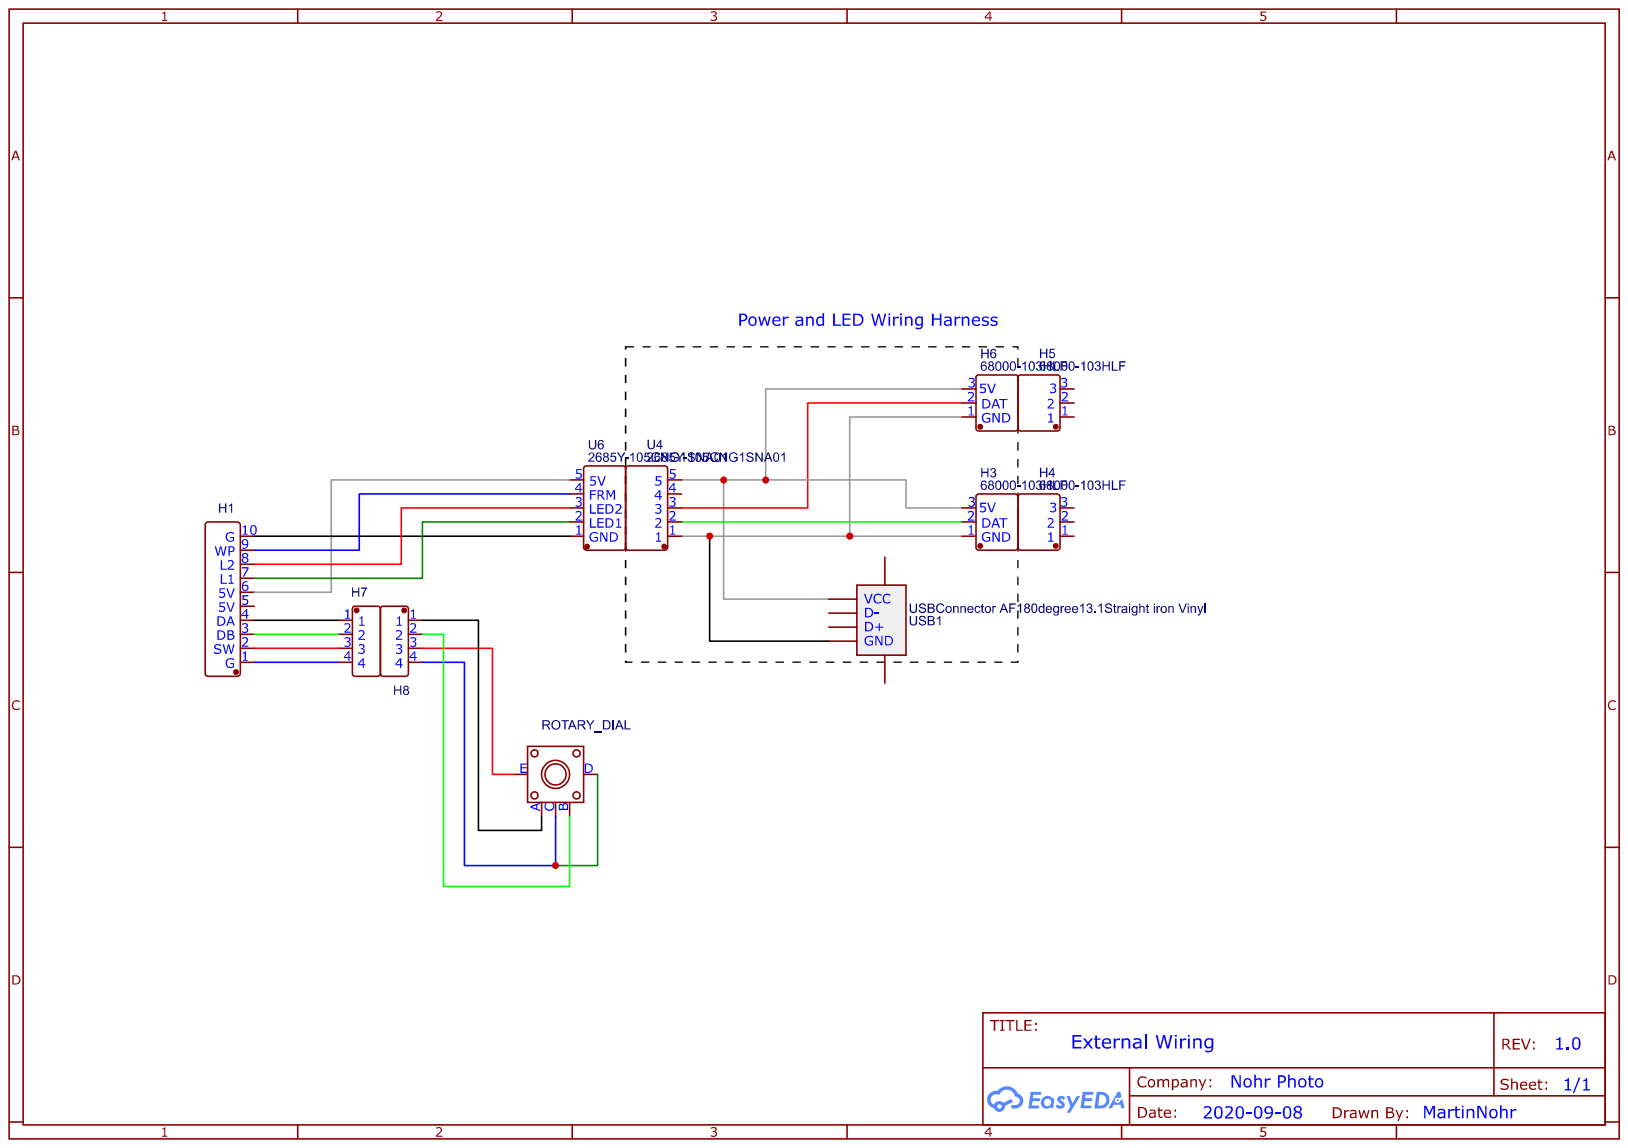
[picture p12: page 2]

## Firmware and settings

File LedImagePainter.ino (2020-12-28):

/*
 Name:		LedImagePainter.ino
 Created:	8/5/2020 9:50:12 PM
 Author:	Martin
*/
/*
 Martin Nohr ESP32 LED Image Painter
*/
/*
	BLE code based on Neil Kolban example for IDF: https://github.com/nkolban/esp32-snippets/blob/master/cpp_utils/tests/BLE%20Tests/SampleServer.cpp
*/
#include "LedImagePainter.h"

RTC_DATA_ATTR int nBootCount = 0;

// some forward references that Arduino IDE needs
int IRAM_ATTR readByte(bool clear);
void IRAM_ATTR ReadAndDisplayFile(bool doingFirstHalf);
uint16_t IRAM_ATTR readInt();
uint32_t IRAM_ATTR readLong();
void IRAM_ATTR FileSeekBuf(uint32_t place);

//static const char* TAG = "lightwand";
//esp_timer_cb_t oneshot_timer_callback(void* arg)
void IRAM_ATTR oneshot_LED_timer_callback(void* arg)
{
	bStripWaiting = false;
	//int64_t time_since_boot = esp_timer_get_time();
	//Serial.println("in isr");
	//ESP_LOGI(TAG, "One-shot timer called, time since boot: %lld us", time_since_boot);
}

class MyServerCallbacks : public BLEServerCallbacks {
	void onConnect(BLEServer* pServer) {
		BLEDeviceConnected = true;
		//OLED->clear();
		//WriteMessage("BLE connected");
		//OLED->clear();
		//DisplayCurrentFile();
		//Serial.println("BLE connected");
	};

	void onDisconnect(BLEServer* pServer) {
		BLEDeviceConnected = false;
		//OLED->clear();
		//WriteMessage("BLE disconnected");
		//OLED->clear();
		//DisplayCurrentFile();
		//Serial.println("BLE disconnected");
	}
};

class MyCharacteristicCallbacks : public BLECharacteristicCallbacks {
	void onWrite(BLECharacteristic* pCharacteristic) {
		BLEUUID uuid = pCharacteristic->getUUID();
		//Serial.println("UUID:" + String(uuid.toString().c_str()));
		std::string value = pCharacteristic->getValue();
		//String stmp = value.c_str();

		if (value.length() > 0) {
			//Serial.println("*********");
			//Serial.print("New value: ");
			//for (int i = 0; i < value.length(); i++) {
			//	Serial.print(value[i]);
			//}
			//Serial.println();
			//Serial.println("*********");
			// see if this a UUID we can change
			if (uuid.equals(BLEUUID(CHARACTERISTIC_UUID_RUN))) {
				sBLECommand = value;
			}
			else if (uuid.equals(BLEUUID(CHARACTERISTIC_UUID_WANDSETTINGS))) {
				//Serial.println(value.c_str());
				ARDUINOJSON_NAMESPACE::StaticJsonDocument<200> doc;
				const char* json = value.c_str();

				// Deserialize the JSON document
				DeserializationError error = deserializeJson(doc, json);

				// Test if parsing succeeds.
				if (error) {
					//Serial.print("deserializeJson() failed: ");
					//Serial.println(error.c_str());
					return;
				}
				JsonObject object = doc.as<JsonObject>();
				// see if brightness is there
				JsonVariant jv = doc.getMember("bright");
				if (!jv.isNull()) {
					nStripBrightness = jv.as<int>();
				}
				// see if repeat
				jv = doc.getMember("repeatcount");
				if (!jv.isNull()) {
					repeatCount = jv.as<int>();
				}
				// see if repeat delay
				jv = doc.getMember("repeatdelay");
				if (!jv.isNull()) {
					repeatDelay = jv.as<int>();
				}
				// change the current file
				jv = doc.getMember("current");
				if (!jv.isNull()) {
					String fn = jv.as<char*>();
					// lets search for the file
					int ix = LookUpFile(fn);
					if (ix != -1) {
						CurrentFileIndex = ix;
						DisplayCurrentFile();
					}
				}
				// change framehold
				jv = doc.getMember("framehold");
				if (!jv.isNull()) {
					nFrameHold = jv.as<int>();
				}
				// change builtin setting
				jv = doc.getMember("builtin");
				if (!jv.isNull()) {
					String bist = jv.as<char*>();
					bist.toUpperCase();
					bool bi = bist[0] == 'T';
					if (bi != bShowBuiltInTests) {
						ToggleFilesBuiltin(NULL);
						//Serial.println("builtin:" + String(bShowBuiltInTests ? "true" : "false"));
						CurrentFileIndex = 0;
						OLED->clear();
						DisplayCurrentFile();
					}
				}
			}
			//else if (uuid.equals(BLEUUID(CHARACTERISTIC_UUID_LEDBRIGHT))) {
			//	nStripBrightness = stmp.toInt();
			//	nStripBrightness = constrain(nStripBrightness, 1, 100);
			//}
			//else if (uuid.equals(BLEUUID(CHARACTERISTIC_UUID_BUILTIN))) {
			//	stmp.toUpperCase();
			//	bool newval = stmp.equals("TRUE") ? true : false;
			//	//Serial.println("newval:" + String(newval ? "true" : "false"));
			//	if (newval != bShowBuiltInTests) {
			//		//Serial.println("builtin:" + String(bShowBuiltInTests ? "true" : "false"));
			//		ToggleFilesBuiltin(NULL);
			//		//Serial.println("builtin:" + String(bShowBuiltInTests ? "true" : "false"));
			//		OLED->clear();
			//		DisplayCurrentFile();
			//	}
			//}
			//else if (uuid.equals(BLEUUID(CHARACTERISTIC_UUID_2LEDSTRIPS))) {
			//	stmp.toUpperCase();
			//	bSecondStrip = stmp.compareTo("TRUE") == 0 ? true : false;
			//}
			else if (uuid.equals(BLEUUID(CHARACTERISTIC_UUID_FILEINFO))) {
				// change the current file here, maybe we search for it?
			}
			//else if (uuid.equals(BLEUUID(CHARACTERISTIC_UUID_FRAMETIME))) {
			//	frameHold = stmp.toInt();
			//}
			//else if (uuid.equals(BLEUUID(CHARACTERISTIC_UUID_STARTDELAY))) {
			//	startDelay = stmp.toInt();
			//}
			UpdateBLE(false);
		}
	}
};

void EnableBLE()
{
	BLEDevice::init("MN LED Image Painter");
	BLEServer* pServer = BLEDevice::createServer();
	pServer->setCallbacks(new MyServerCallbacks());

	BLEService* pServiceDevInfo = pServer->createService(BLEUUID((uint16_t)0x180a));
	BLECharacteristic* pCharacteristicDevInfo = pServiceDevInfo->createCharacteristic(
		BLEUUID((uint16_t)0x2a29),
		BLECharacteristic::PROPERTY_READ
	);
	pCharacteristicDevInfo->setValue("NOHR PHOTO");

	pCharacteristicDevInfo = pServiceDevInfo->createCharacteristic(
		BLEUUID((uint16_t)0x2a24),	// model
		BLECharacteristic::PROPERTY_READ
	);
	pCharacteristicDevInfo->setValue("LED Image Painter Small Display");

	pCharacteristicDevInfo = pServiceDevInfo->createCharacteristic(
		BLEUUID((uint16_t)0x2a28),	// software version
		BLECharacteristic::PROPERTY_READ
	);
	pCharacteristicDevInfo->setValue("1.1");

	pCharacteristicDevInfo = pServiceDevInfo->createCharacteristic(
		BLEUUID((uint16_t)0x2a27),	// hardware version
		BLECharacteristic::PROPERTY_READ
	);
	pCharacteristicDevInfo->setValue("1.0");

	BLEService* pService = pServer->createService(SERVICE_UUID);
	// filepath
	pCharacteristicFileInfo = pService->createCharacteristic(
		CHARACTERISTIC_UUID_FILEINFO,
		BLECharacteristic::PROPERTY_READ |
		BLECharacteristic::PROPERTY_WRITE
	);
	// Create a BLE Descriptor
	//pCharacteristicFilename->addDescriptor(new BLE2902());

	// Wand settins
	pCharacteristicWandSettings = pService->createCharacteristic(
		CHARACTERISTIC_UUID_WANDSETTINGS,
		BLECharacteristic::PROPERTY_READ |
		BLECharacteristic::PROPERTY_WRITE
	);

	// run command
	pCharacteristicRun = pService->createCharacteristic(
		CHARACTERISTIC_UUID_RUN,
		BLECharacteristic::PROPERTY_READ |
		BLECharacteristic::PROPERTY_WRITE
	);

	// all the filenames
	pCharacteristicFileList = pService->createCharacteristic(
		CHARACTERISTIC_UUID_FILELIST,
		BLECharacteristic::PROPERTY_READ
	);

	// add anybody that can be changed or can call us with something to do
	MyCharacteristicCallbacks* pCallBacks = new MyCharacteristicCallbacks();
	pCharacteristicRun->setCallbacks(pCallBacks);
	pCharacteristicWandSettings->setCallbacks(pCallBacks);
	pCharacteristicFileInfo->setCallbacks(pCallBacks);
	UpdateBLE(false);
	pService->start();
	pServiceDevInfo->start();
	BLEAdvertising* pAdvertising = BLEDevice::getAdvertising();
	pAdvertising->addServiceUUID(SERVICE_UUID);
	pAdvertising->addServiceUUID(BLEUUID((uint16_t)0x180a));
	pAdvertising->setScanResponse(true);
	pAdvertising->setMinPreferred(0x06);  // functions that help with iPhone connections issue
	pAdvertising->setMinPreferred(0x12);
	BLEDevice::startAdvertising();
}

void setup()
{
	Serial.begin(115200);
	delay(100);
	//Serial.println("boot: " + String(nBootCount));
	CRotaryDialButton::getInstance()->begin(BTN_A, BTN_B, BTN_PUSH);
	setupSDcard();
	gpio_set_direction((gpio_num_t)LED, GPIO_MODE_OUTPUT);
	digitalWrite(LED, HIGH);
	gpio_set_direction(FRAMEBUTTON, GPIO_MODE_INPUT);
	gpio_set_pull_mode(FRAMEBUTTON, GPIO_PULLUP_ONLY);
	oneshot_LED_timer_args = {
				oneshot_LED_timer_callback,
				/* argument specified here will be passed to timer callback function */
				(void*)0,
				ESP_TIMER_TASK,
				"one-shotLED"
	};
	esp_timer_create(&oneshot_LED_timer_args, &oneshot_LED_timer);

	Heltec.begin(true /*DisplayEnable Enable*/, false /*LoRa Enable*/, true /*Serial Enable*/);
	delay(100);
	digitalWrite(LED, LOW);
	int width = OLED->width();
	int height = OLED->height();
	OLED->clear();
	if (nBootCount == 0) {
		OLED->drawRect(0, 0, width - 1, height - 1);
		OLED->setFont(ArialMT_Plain_24);
		OLED->drawString(2, 2, "LEDPainter");
		OLED->setFont(ArialMT_Plain_16);
		OLED->drawString(4, 30, "Version 2.17");
		OLED->setFont(ArialMT_Plain_10);
		OLED->drawString(4, 48, __DATE__);
		OLED->display();
	}
	//OLED->setFont(ArialMT_Plain_10);
	charHeight = 13;

	EEPROM.begin(1024);
	// this will fix the signature if necessary
	if (SaveSettings(false, true)) {
		// get the autoload flag
		SaveSettings(false, false, true);
	}
	// load the saved settings if flag is true and the button isn't pushed
	if ((nBootCount == 0) && bAutoLoadSettings && gpio_get_level(BTN_PUSH)) {
		// read all the settings
		SaveSettings(false);
	}

	menuPtr = new MenuInfo;
	MenuStack.push(menuPtr);
	MenuStack.peek()->menu = MainMenu;
	MenuStack.peek()->index = 0;
	MenuStack.peek()->offset = 0;
	//const int ledPin = 16;  // 16 corresponds to GPIO16

	//// configure LED PWM functionalitites
	//ledcSetup(ledChannel, freq, resolution);
	//// attach the channel to the GPIO to be controlled
	//ledcAttachPin(WandPin, ledChannel);
	//ledcWrite(ledChannel, 200);
	FastLED.addLeds<NEOPIXEL, DATA_PIN1>(leds, 0, NUM_LEDS);
	//FastLED.addLeds<NEOPIXEL, DATA_PIN2>(leds, 0, NUM_LEDS);	// to test parallel second strip
	//if (bSecondStrip)
	// create the second led controller
	FastLED.addLeds<NEOPIXEL, DATA_PIN2>(leds, NUM_LEDS, NUM_LEDS);
	//FastLED.setTemperature(whiteBalance);
	FastLED.setTemperature(CRGB(whiteBalance.r, whiteBalance.g, whiteBalance.b));
	FastLED.setBrightness(nStripBrightness);
	if (nBootCount == 0) {
		//bool oldSecond = bSecondStrip;
		//bSecondStrip = true;
		RainbowPulse();
		//bSecondStrip = oldSecond;
		//// Turn the LED on, then pause
		//SetPixel(0, CRGB::Red);
		//SetPixel(1, CRGB::Red);
		//SetPixel(4, CRGB::Green);
		//SetPixel(5, CRGB::Green);
		//SetPixel(8, CRGB::Blue);
		//SetPixel(9, CRGB::Blue);
		//SetPixel(12, CRGB::White);
		//SetPixel(13, CRGB::White);
		//SetPixel(NUM_LEDS - 0, CRGB::Red);
		//SetPixel(NUM_LEDS - 1, CRGB::Red);
		//SetPixel(NUM_LEDS - 4, CRGB::Green);
		//SetPixel(NUM_LEDS - 5, CRGB::Green);
		//SetPixel(NUM_LEDS - 8, CRGB::Blue);
		//SetPixel(NUM_LEDS - 9, CRGB::Blue);
		//SetPixel(NUM_LEDS - 12, CRGB::White);
		//SetPixel(NUM_LEDS - 13, CRGB::White);
		//SetPixel(0 + NUM_LEDS, CRGB::Red);
		//SetPixel(1 + NUM_LEDS, CRGB::Red);
		//SetPixel(4 + NUM_LEDS, CRGB::Green);
		//SetPixel(5 + NUM_LEDS, CRGB::Green);
		//SetPixel(8 + NUM_LEDS, CRGB::Blue);
		//SetPixel(9 + NUM_LEDS, CRGB::Blue);
		//SetPixel(12 + NUM_LEDS, CRGB::White);
		//SetPixel(13 + NUM_LEDS, CRGB::White);
		//for (int ix = 0; ix < 255; ix += 5) {
		//	FastLED.setBrightness(ix);
		//	FastLED.show();
		//	delayMicroseconds(50);
		//}
		//for (int ix = 255; ix >= 0; ix -= 5) {
		//	FastLED.setBrightness(ix);
		//	FastLED.show();
		//	delayMicroseconds(50);
		//}
		//delayMicroseconds(50);
		//FastLED.clear(true);
		//delayMicroseconds(50);
		//FastLED.setBrightness(nStripBrightness);
		//delay(50);
		//// Now turn the LED off
		//FastLED.clear(true);
		//delayMicroseconds(50);
		//// run a white dot up the display and back
		//for (int ix = 0; ix < STRIPLENGTH; ++ix) {
		//	SetPixel(ix, CRGB::White);
		//	if (ix)
		//		SetPixel(ix - 1, CRGB::Black);
		//	FastLED.show();
		//	delayMicroseconds(50);
		//}
		//for (int ix = STRIPLENGTH - 1; ix >= 0; --ix) {
		//	SetPixel(ix, CRGB::White);
		//	if (ix)
		//		SetPixel(ix + 1, CRGB::Black);
		//	FastLED.show();
		//	delayMicroseconds(50);
		//}
	}
	FastLED.clear(true);
	delay(100);
	OLED->clear();
	
	if (bEnableBLE) {
		EnableBLE();
	}
	// wait for button release
	while (!digitalRead(BTN_PUSH))
		;
	delay(30);	// debounce
	while (!digitalRead(BTN_PUSH))
		;
	// clear the button buffer
	CRotaryDialButton::getInstance()->clear();
	if (!bSdCardValid) {
		DisplayCurrentFile();
		delay(2000);
		ToggleFilesBuiltin(NULL);
	}
	DisplayCurrentFile();
/*
	analogSetCycles(8);                   // Set number of cycles per sample, default is 8 and provides an optimal result, range is 1 - 255
	analogSetSamples(1);                  // Set number of samples in the range, default is 1, it has an effect on sensitivity has been multiplied
	analogSetClockDiv(1);                 // Set the divider for the ADC clock, default is 1, range is 1 - 255
	analogSetAttenuation(ADC_11db);       // Sets the input attenuation for ALL ADC inputs, default is ADC_11db, range is ADC_0db, ADC_2_5db, ADC_6db, ADC_11db
	//analogSetPinAttenuation(36, ADC_11db); // Sets the input attenuation, default is ADC_11db, range is ADC_0db, ADC_2_5db, ADC_6db, ADC_11db
	analogSetPinAttenuation(37, ADC_11db);
	// ADC_0db provides no attenuation so IN/OUT = 1 / 1 an input of 3 volts remains at 3 volts before ADC measurement
	// ADC_2_5db provides an attenuation so that IN/OUT = 1 / 1.34 an input of 3 volts is reduced to 2.238 volts before ADC measurement
	// ADC_6db provides an attenuation so that IN/OUT = 1 / 2 an input of 3 volts is reduced to 1.500 volts before ADC measurement
	// ADC_11db provides an attenuation so that IN/OUT = 1 / 3.6 an input of 3 volts is reduced to 0.833 volts before ADC measurement
//   adcAttachPin(VP);                     // Attach a pin to ADC (also clears any other analog mode that could be on), returns TRUE/FALSE result 
//   adcStart(VP);                         // Starts an ADC conversion on attached pin's bus
//   adcBusy(VP);                          // Check if conversion on the pin's ADC bus is currently running, returns TRUE/FALSE result 
//   adcEnd(VP);

	//adcAttachPin(36);
	adcAttachPin(37);
*/
}

void loop()
{
	static bool didsomething = false;
	bool lastStrip = bSecondStrip;
	bool bLastEnableBLE = bEnableBLE;
	//int lastDisplayBrightness = displayBrightness;
	didsomething = bSettingsMode ? HandleMenus() : HandleRunMode();
	// special handling for things that might have changed
	//if (lastDisplayBrightness != displayBrightness) {
	//	OLED->setBrightness(displayBrightness);
	//}
	//if (lastStrip != bSecondStrip) {
		//******** this crashes
		//if (bSecondStrip)
		//	FastLED.addLeds<NEOPIXEL, DATA_PIN2>(leds, NUM_LEDS, NUM_LEDS);
		//else
		//	FastLED.addLeds<NEOPIXEL, DATA_PIN2>(leds, NUM_LEDS, 0);
	//}
	// wait for no keys
	if (didsomething) {
		//Serial.println("calling wait for none");
		UpdateBLE(false);
		didsomething = false;
		// see if BLE enabled
		if (bEnableBLE != bLastEnableBLE) {
			if (bEnableBLE) {
				EnableBLE();
			}
			else {
				// shutdown BLE
				BLEDeviceConnected = false;
				// TODO: is there anything else we need to do here?
			}
		}
		delay(1);
	}
	// disconnecting
	if (!BLEDeviceConnected && oldBLEDeviceConnected) {
		delay(500); // give the bluetooth stack the chance to get things ready
		BLEDevice::startAdvertising();
		//Serial.println("start advertising");
		oldBLEDeviceConnected = BLEDeviceConnected;
	}
	// connecting
	if (BLEDeviceConnected && !oldBLEDeviceConnected) {
		// do stuff here on connecting
		oldBLEDeviceConnected = BLEDeviceConnected;
		UpdateBLE(false);
	}
}

void UpdateBLE(bool bProgressOnly)
{
	// update the settings, except for progress percent which is done in ShowProgress.
	if (BLEDeviceConnected) {
		String js;
		// running information and commands
		DynamicJsonDocument runinfo(256);
		runinfo["running"] = bIsRunning;
		runinfo["progress"] = nProgress;
		runinfo["repeatsleft"] = nRepeatsLeft;
		js = "";
		serializeJson(runinfo, js);
		pCharacteristicRun->setValue(js.c_str());
		if (!bProgressOnly) {
			// file information
			DynamicJsonDocument filesdoc(1024);
			filesdoc["builtin"] = bShowBuiltInTests;
			filesdoc["path"] = currentFolder.c_str();
			filesdoc["current"] = FileNames[CurrentFileIndex].c_str();
			js = "";
			serializeJson(filesdoc, js);
			pCharacteristicFileInfo->setValue(js.c_str());
			// settings
			DynamicJsonDocument wsdoc(1024);
			wsdoc["secondstrip"] = bSecondStrip;
			wsdoc["bright"] = nStripBrightness;
			wsdoc["framehold"] = nFrameHold;
			wsdoc["framebutton"] = nFramePulseCount;
			wsdoc["startdelay"] = startDelay;
			wsdoc["repeatdelay"] = repeatDelay;
			wsdoc["repeatcount"] = repeatCount;
			wsdoc["gamma"] = bGammaCorrection;
			wsdoc["reverse"] = bReverseImage;
			wsdoc["upsidedown"] = bUpsideDown;
			wsdoc["mirror"] = bMirrorPlayImage;
			wsdoc["chain"] = bChainFiles;
			wsdoc["chainrepeats"] = nChainRepeats;
			wsdoc["scaley"] = bScaleHeight;
			js = "";
			serializeJson(wsdoc, js);
			pCharacteristicWandSettings->setValue(js.c_str());
			// file list
			DynamicJsonDocument filelist(512);
			filelist["builtin"] = bShowBuiltInTests;
			filelist["path"] = currentFolder.c_str();
			filelist["count"] = FileNames.size();
			filelist["ix"] = CurrentFileIndex;
			JsonArray data = filelist.createNestedArray("files");
			for (auto st : FileNames) {
				data.add(st.c_str());
			}
			js = "";
			serializeJson(filelist, js);
			pCharacteristicFileList->setValue(js.c_str());
		}
	}
}

bool RunMenus(int button)
{
	// save this so we can see if we need to save a new changed value
	bool lastAutoLoadFlag = bAutoLoadSettings;
	// see if we got a menu match
	bool gotmatch = false;
	int menuix = 0;
	MenuInfo* oldMenu;
	bool bExit = false;
	for (int ix = 0; !gotmatch && MenuStack.peek()->menu[ix].op != eTerminate; ++ix) {
		// see if this is one is valid
		if (!MenuStack.peek()->menu[ix].valid) {
			continue;
		}
		//Serial.println("menu button: " + String(button));
		if (button == BTN_SELECT && menuix == MenuStack.peek()->index) {
			//Serial.println("got match " + String(menuix) + " " + String(MenuStack.peek()->index));
			gotmatch = true;
			//Serial.println("clicked on menu");
			// got one, service it
			switch (MenuStack.peek()->menu[ix].op) {
			case eText:
			case eTextInt:
			case eTextCurrentFile:
			case eBool:
				bMenuChanged = true;
				if (MenuStack.peek()->menu[ix].function) {
					(*MenuStack.peek()->menu[ix].function)(&MenuStack.peek()->menu[ix]);
				}
				break;
			case eList:
				bMenuChanged = true;
				if (MenuStack.peek()->menu[ix].function) {
					(*MenuStack.peek()->menu[ix].function)(&MenuStack.peek()->menu[ix]);
				}
				bExit = true;
				// if there is a value, set the min value in it
				if (MenuStack.peek()->menu[ix].value) {
					*(int*)MenuStack.peek()->menu[ix].value = MenuStack.peek()->menu[ix].min;
				}
				break;
			case eMenu:
				if (MenuStack.peek()->menu) {
					oldMenu = MenuStack.peek();
					MenuStack.push(new MenuInfo);
					MenuStack.peek()->menu = oldMenu->menu[ix].menu;
					bMenuChanged = true;
					MenuStack.peek()->index = 0;
					MenuStack.peek()->offset = 0;
					//Serial.println("change menu");
					// check if the new menu is an eList and if it has a value, if it does, set the index to it
					if (MenuStack.peek()->menu->op == eList && MenuStack.peek()->menu->value) {
						int ix = *(int*)MenuStack.peek()->menu->value;
						MenuStack.peek()->index = ix;
						// adjust offset if necessary
						if (ix > 4) {
							MenuStack.peek()->offset = ix - 4;
						}
					}
				}
				break;
			case eBuiltinOptions: // find it in builtins
				if (BuiltInFiles[CurrentFileIndex].menu != NULL) {
					MenuStack.peek()->index = MenuStack.peek()->index;
					MenuStack.push(new MenuInfo);
					MenuStack.peek()->menu = BuiltInFiles[CurrentFileIndex].menu;
					MenuStack.peek()->index = 0;
					MenuStack.peek()->offset = 0;
				}
				else {
					WriteMessage("No settings available for:\n" + String(BuiltInFiles[CurrentFileIndex].text));
				}
				bMenuChanged = true;
				break;
			case eExit: // go back a level
				bExit = true;
				break;
			case eReboot:
				WriteMessage("Rebooting in 2 seconds\nHold button for factory reset", false, 2000);
				ESP.restart();
				break;
			}
		}
		++menuix;
	}
	// if no match, and we are in a submenu, go back one level, or if bExit is set
	if (bExit || (!bMenuChanged && MenuStack.count() > 1)) {
		bMenuChanged = true;
		menuPtr = MenuStack.pop();
		delete menuPtr;
	}
	// see if the autoload flag changed
	if (bAutoLoadSettings != lastAutoLoadFlag) {
		// the flag is now true, so we should save the current settings
		SaveSettings(true, false, true);
	}
}
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
//void loop()
//{
//	int val1 = 0;
//	int val2 = 0;
//	int val3 = 0;
//	for (int i = 0; i < TWO_HUNDRED_PI; i++) {
//		val1 = round(255 / 2.0 * (sin(i / 100.0) + 1));
//		val2 = round(255 / 2.0 * (sin(i / 100.0 + TWO_THIRDS_PI) + 1));
//		val3 = round(255 / 2.0 * (sin(i / 100.0 - TWO_THIRDS_PI) + 1));
//
//		leds[7] = CHSV(0, 255, val1);
//		leds[8] = CHSV(96, 255, val2);
//		leds[9] = CHSV(160, 255, val3);
//
//		FastLED.show();
//
//		delay(1);
//	}
//}

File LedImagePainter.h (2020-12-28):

#pragma once

// ***** Various switchs for options are set here *****
// SB with rotary switch, 0 for original, 1 for first PCB, 2 for 2nd PCB
//#define PCB_WITH_DIAL 0
//#define PCB_WITH_DIAL 1
#define PCB_WITH_DIAL 2
// 1 for HELTEC, 0 for TTGO
#define USE_HELTEC_SBC 1
// 1 for standard SD library, 0 for the new exFat library
#define USE_STANDARD_SD 1
// *****

#include <ArduinoJson.h>
#include <BLEDevice.h>
#include <BLEUtils.h>
#include <BLEServer.h>
#include <BLE2902.h>
#if USE_HELTEC_SBC
    #include "heltec.h"
#else
    #include <TFT_eSPI.h> // Hardware-specific library
#endif
#include <time.h>
#if USE_STANDARD_SD
    #include "SD.h"
#else
    #include <SdFatConfig.h>
    #include <sdfat.h>
#endif
#include "SPI.h"
#include <FastLED.h>
#include "morefonts.h"
#include <EEPROM.h>
#include "RotaryDialButton.h"
#include <vector>
//#include <stack>
//std::stack<int> menuStack;

#define BTN_SELECT  CRotaryDialButton::BTN_CLICK
#define BTN_NONE    CRotaryDialButton::BTN_NONE
#define BTN_LEFT    CRotaryDialButton::BTN_LEFT
#define BTN_RIGHT   CRotaryDialButton::BTN_RIGHT
#define BTN_LONG    CRotaryDialButton::BTN_LONGPRESS

#if PCB_WITH_DIAL==0
#define BTN_PUSH GPIO_NUM_27
#define BTN_A GPIO_NUM_12
#define BTN_B GPIO_NUM_14
#elif PCB_WITH_DIAL==1
#define BTN_PUSH GPIO_NUM_12
#define BTN_A GPIO_NUM_14
#define BTN_B GPIO_NUM_27
#elif PCB_WITH_DIAL==2
#define BTN_PUSH GPIO_NUM_27
#define BTN_A GPIO_NUM_14
#define BTN_B GPIO_NUM_12
#endif

#define FRAMEBUTTON GPIO_NUM_26

#if USE_HELTEC_SBC
#define OLED Heltec.display
#else
#endif

// bluetooth stuff
// See the following for generating UUIDs:
// https://www.uuidgenerator.net/
#define SERVICE_UUID					    "4fafc201-1fb5-459e-8fcc-c5c9c331914b"
#define CHARACTERISTIC_UUID_FILEINFO	    "4faf0000-1fb5-459e-8fcc-c5c9c331914b"
#define CHARACTERISTIC_UUID_WANDSETTINGS	"4faf0100-1fb5-459e-8fcc-c5c9c331914b"
#define CHARACTERISTIC_UUID_RUN			    "4faf0200-1fb5-459e-8fcc-c5c9c331914b"
#define CHARACTERISTIC_UUID_FILELIST	    "4faf0300-1fb5-459e-8fcc-c5c9c331914b"

BLECharacteristic* pCharacteristicFileInfo = NULL;
BLECharacteristic* pCharacteristicWandSettings = NULL;
BLECharacteristic* pCharacteristicRun = NULL;
BLECharacteristic* pCharacteristicFileList = NULL;
std::string sBLECommand = ""; // remote commands come in here
volatile bool BLEDeviceConnected = false;
volatile bool oldBLEDeviceConnected = false;
bool bEnableBLE = false;

// functions
void UpdateBLE(bool bProgressOnly);
void DisplayCurrentFile(bool path = true);
void DisplayLine(int line, String text, bool bOverRide = false);
void DisplayMenuLine(int line, int displine, String text);
void fixRGBwithGamma(byte* rp, byte* gp, byte* bp);
void WriteMessage(String txt, bool error = false, int wait = 2000);
void BarberPole();
void TestBouncingBalls();
void CheckerBoard();
void RandomBars();
void RunningDot();
void OppositeRunningDots();
void TestTwinkle();
void TestMeteor();
void TestCylon();
void TestRainbow();
void TestJuggle();
void TestSine();
void TestBpm();
void TestConfetti();
void DisplayAllColor();
void TestStripes();
void TestLines();
void RainbowPulse();
void TestWedge();

bool bPauseDisplay = false; // set this so DisplayLine and Progress won't update display
CRotaryDialButton::Button ReadButton();
bool CheckCancel();

// eeprom values
// the signature is saved first in eeprom, followed by the autoload flag, all other values follow
char signature[] = { "LIP0217" };   // set to make sure saved values are valid, change when savevalues is changed
RTC_DATA_ATTR bool bAutoLoadSettings = false;     // set to automatically load saved settings from eeprom
bool SaveSettings(bool save, bool bOnlySignature = false, bool bAutoloadFlag = false);
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

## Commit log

2020-08-07 Added in rotary switch code.
2020-08-07 Started switching over to rotary control.
2020-08-07 Button handling slightly better.
2020-08-10 Works with single rotary button now. Integers are accepted with long press. Single press toggles the increment amount. Long press from menu returns to run mode and remembers menu entry. Long press en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
2020-08-11 Added longpress button when it happens instead of waiting until released. This is better user interface.
2020-08-13 Add files via upload
    Schematic for image painter. Shows three sections, the ESP32 box, the rotary button, and the battery with connections.
2020-08-13 Added USB battery connector.
    Also cleaned up the layout to make it easier to build.
2020-08-14 Added LED wire colors.
2020-08-16 Added logic level shifter
    The WS2812 LED strips need 5 volts, the ESP32 is 3.3 volts.
2020-08-19 Added input for advancing the frame after N pulses. This will allow a wheel with contact closures to control the frame advancing.
2020-08-20 Added gamma correction to the menus, and allowed brightness to be 0 for the very lowest setting, it maps to 1 of 255.
    [LedImagePainter.h, LedImagePainter.ino]
2020-08-20 Atempted fixes for button being missed sometimes.
    [LedImagePainter.ino]
2020-08-20 Longpress to cancel file run. Added BLE enable setting. Removed usleep()'s in case they were causing the button to fail.
    [LedImagePainter.h, LedImagePainter.ino]
2020-08-21 Debugging version for keypresses missed. Fixed cancel chain run. Changed repeat counts to go from n to 1 instead n-1 to 0.
    [LedImagePainter.ino]
2020-08-21 Slightly improved button int handling. Check to see what it was last time, and change if it isn't different.
2020-08-21 Much improved button handling. Seems to work better now.
2020-08-22 Fixed button pressing, it is I think much better now.
    [LedImagePainter.h, LedImagePainter.ino]
2020-08-22 Fixed display problems with repeats and chains.
    [LedImagePainter.ino]
2020-08-22 Attempt to fix load defaults. The autoload arg might have been wrong.
    [LedImagePainter.ino]
2020-08-22 Fixed bug when returning to previous menu.
    [LedImagePainter.ino]
2020-08-22 Added manual click frame advance.
2020-08-22 Fixed minor bug in menu scrolling down.
    [LedImagePainter.ino]
2020-08-23 Added reset to integer entry user interface.
    [LedImagePainter.ino]
2020-08-24 Fixed menu blinking and added return to previous menu as first line of each menu.
    [LedImagePainter.h, LedImagePainter.ino]
2020-08-24 Fixed double pixel addressing.
    [LedImagePainter.ino]
2020-08-24 Removed old button timer that is no longer used.
    [LedImagePainter.h, LedImagePainter.ino]
2020-08-25 Eliminated LEDIX to a function call and put the upside down and pixel doubling handling in there. This makes it work with many of the built-ins.
2020-08-27 Added error message if macro file not found.
    [LedImagePainter.ino]
2020-08-27 Some fixes for folder support in macros.
    [LedImagePainter.ino]
2020-08-27 Need to save and restore current folder around running a macro.
2020-08-27 Fixed folder files running from macros.
    [LedImagePainter.ino]
2020-08-27 Don't reload SD if folder hasn't changed when running a macro. Doing so was slowing it down a lot. Also save the settings so macros won't change them.
    [LedImagePainter.ino]
2020-08-27 Added save macro command which will just record the settings. Added a load macro command that doesn't save/restore the settings.
    [LedImagePainter.h, LedImagePainter.ino]
2020-08-28 Simplified wheel reading by just handling interrupts for A and then looking at the state of B. It seems more reliable.
2020-08-28 Fixed blinking during macro running with repeats.
    [LedImagePainter.ino]
2020-08-30 Fixed menu scrolling when menu wrap is on. It wasn't refreshing the display and setting the offset correctly.
    [LedImagePainter.ino]
2020-08-30 Fixed autoload settings problems.
    [LedImagePainter.h, LedImagePainter.ino]
2020-08-30 Changed button timeout to 2mS, it seems to be enough after looking at some 'scope tracings.
2020-08-30 Fixed the cancel macro operation.
    [LedImagePainter.ino]
2020-08-30 Fixed running macros after a cancel. Fixed 1 second runtime of rainbow.
    [LedImagePainter.ino]
2020-09-01 Fixed bAutoload settings when it was initially something other than 0 or 1. Changed pinMode() calls to gpio_set_pull_mode because the pinMode for port 14 didn't work on esp32.
    [LedImagePainter.ino]
2020-09-01 Added chain delay.
2020-09-01 Fixed chain delay display. Used repeat delay also repeating chains.
    [LedImagePainter.ino]
2020-09-02 Added framehold and builtin BLE commands.
2020-09-02 Allow 32 bouncing balls. Fix display when running built-ins. A line wasn't being cleared.
    [LedImagePainter.h, LedImagePainter.ino]
2020-09-05 Added wheel encode connector and fixed A B wiring
2020-09-05 Some fixes for macro menus.
    [LedImagePainter.h, LedImagePainter.ino]
2020-09-05 Fixed the new macro menu so it works. It also returns to the previous menu after selection.
    [LedImagePainter.h, LedImagePainter.ino]
2020-09-07 Put '-' in front of previous menu commands. In eList menus, move the '*' to the current setting.
2020-09-08 Fixed macro repeat delay to show the '.' for tenths of seconds.
    [LedImagePainter.ino]
2020-09-20 Added reverse dial direction option.
    [LedImagePainter.h, LedImagePainter.ino]
2020-09-21 Improved the switch reading code and added a setting to control the length of the long press.
2020-09-22 Don't show chain count when builtins selected.
2020-09-22 Added invert display option for black on white or white on black.
    [LedImagePainter.h, LedImagePainter.ino]
2020-09-22 Changed the normal walking direction from left to right. It was from right to left, but is more awkward for right handers and is also slower to read the bmp file, since it must be read in reverse. Di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
    [LedImagePainter.h, LedImagePainter.ino]
2020-09-23 Changed reverse to direction L-R or R-L.
    [LedImagePainter.h]
2020-09-25 Frame advance menu changes.
2020-09-25 Added adjustable delay between mirror image havles. Fix pixle doubling when two strips installed.
    [LedImagePainter.h, LedImagePainter.ino]
2020-09-27 Fixed the comment for the strip brightness, it goes from 1 to 255.
    [LedImagePainter.h]
2020-10-01 Added option to use a fixed image time instead of a fixed frame time. The actual frame hold time will be calculated depending on the number of frames.
    [LedImagePainter.h, LedImagePainter.ino]
2020-10-02 menu change on fixed/frame to frame/fixed
    [LedImagePainter.h]
2020-10-03 Updated schematic
2020-10-03 EasyEDA project big board
    This is the larger PCB for the original box.
2020-10-04 Fusion 360 and STL files
    [esp Spinner Handle v2.f3d, esp Spinner Handle v2.stl, esp handle tower v8.f3d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]
2020-10-04 Set the correct pins for the single pcb model. Set the display brightness after reading the values on boot. Fixed many issues with saved settings not working correctly on initial programming of ESP32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
    [LedImagePainter.h, LedImagePainter.ino]
2020-10-05 Fixed repeat delay do it doesn't delay after the final run.
    [LedImagePainter.ino]
2020-10-05 Fixed combinations of repeat and chain delays. They were delaying after the final run which isn't necessary.
    [LedImagePainter.ino]
2020-10-05 Don't need to save and restore framehold during file display.
2020-10-06 latest version of the single PCB version
2020-10-06 Fixed version of single PCB
    Corrected rotary dial connections.
2020-10-07 Fixed the frame calculation when doing the fixed time display. It needed to run one loop first so we have the minimum loop time.
    [LedImagePainter.ino]
2020-10-18 Made fixed time the default, rather than fixed frame times.
    [LedImagePainter.h]
2020-10-25 Added sleep menu item. Wakes with button push.
2020-11-04 Removed the sleep command, It doesn't work because the USB power pack turns off due to too little power draw.
    [LedImagePainter.h]
2020-11-06 Made frame time default, makes more sense since images can have different lengths.
2020-11-15 Arduino IDE changes.
2020-11-21 Experimental battery code.
2020-11-22 Added the RainbowPulse to built-ins. This is also called at startup to test LED strip.
2020-11-27 Fixed at least one problem with 288 pixels. The range checker in AdjustStripIndex() was wrong. Changed the startup code to always try both strips to give an indication of them working.
    [LedImagePainter.ino]
2020-11-27 Fixed two strip handling in juggle, lines, and stripes built-in function.
    [LedImagePainter.ino]
2020-11-27 Fixed lines to clear at end.
    [LedImagePainter.ino]
2020-11-27 Fixed rainbow for two strips. Not tested yet though, but it should work now!
    [LedImagePainter.ino]
2020-12-04 Finished the dial sensitivity code. It might need some more tuning but it does seem to work. There are two new entries in the system menu, dial sensitivity and dial speed. Sensitivity is how many cli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
2020-12-17 pinMode(14, PULLUP) doesn't seem to work, so changed to the gpio calls, working now. This code includes the rotary button class now.
    [LedImagePainter.h, LedImagePainter.ino]
2020-12-17 Removed debug Serial println from rotary dial. It caused a crash when rotating too fast and isn't needed anyway.
    [LedImagePainter.h]
2020-12-17 Switched FileNames to std::vector class. Don't need file count or max any more. Use std::sort instead of local isort().
2020-12-24 Changed image rotation to CCW instead of CW. This makes recording macros more rational, they will be in the correct order. Like spelling words with letters as an example.
    [LedImagePainter.h, LedImagePainter.ino]
2020-12-28 Fixed SendFile so it can handle filenames longer than 13 characters total. This was leftover from some old 8.3 filename code.
    [LedImagePainter.ino]
2020-12-28 Added switch definitions for the latest PCB.
2020-12-29 Fixed file chaining in folders.
